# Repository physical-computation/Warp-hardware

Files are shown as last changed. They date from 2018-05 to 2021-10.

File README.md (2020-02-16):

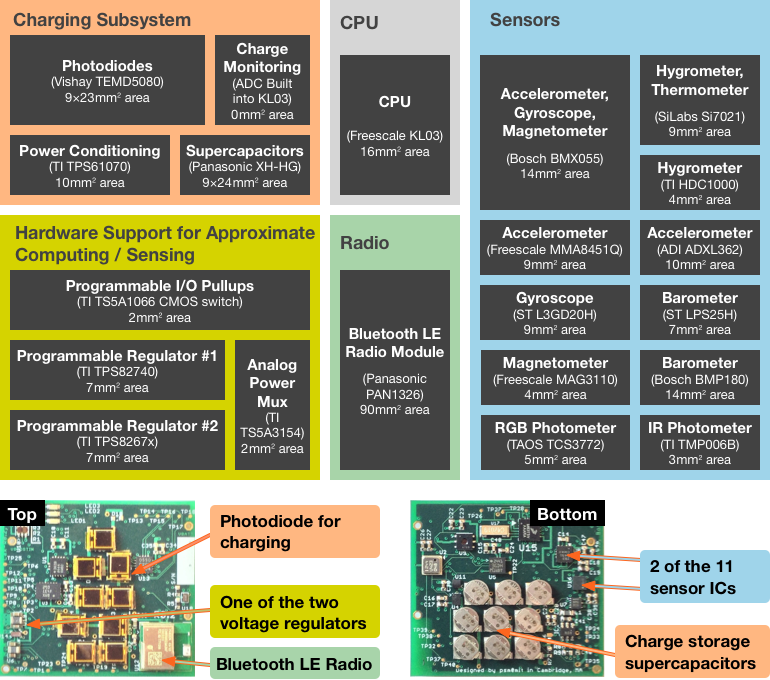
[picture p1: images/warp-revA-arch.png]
Warp


**The Warp hardware platform integrates 21 sensors in a complete system that is 3.6cmx3.3cm**
- - - - 

# Warp
Warp is a hardware platform for efficient multi-modal sensing with adaptive approximation. The hardware contains 11 sensor integrated circuits (ICs) and a total of 21 different sensors. The design includes circuit-level facilities for trading sensor accuracy for power dissipation, and circuit-level facilities for trading sensor communication reliability for power dissipation. The sensors in Warp cover eight sensing modalities: temperature, pressure, 3-axis acceleration, 3-axis angular velocity, 3-axis magnetic flux density, humidity, infrared, color/light (615nm, 525nm, 465nm).

## Prerequisites
We provide the hardware design files in the Eagle CAD format. You can use the free version of Eagle for MacOS, Linux, Windows to view the files. The design is a 10-layer PCB. You will need the full version of Eagle to make modifications. [For academics, the full version of Eagle (Eagle Professional) is completely free](https://knowledge.autodesk.com/support/eagle/learn-explore/caas/sfdcarticles/sfdcarticles/Eagle-Education.html). For non-university hobbyists, Eagle is relatively inexpensive and can also be purchased on a month-at-a-time subscription.

We also provide the hardware design files as Gerbers. You can use any of the numerous free Gerber viewers to view the design.

## Getting boards manufactured
The repository contains detailed instructions for getting the boards manufactured. We provide a pre-populated BOM file with part numbers for purchasing the components from Mouser. Before getting your own boards manufactured, it is worthwhile getting in touch with us for a brief discussion of things to be careful about in providing instructions to your board assembly house.

## Adapting the designs
We license the Warp hardware designs under a BSD license. See details in [LICENSE.txt](https://github.com/physical-computation/Warp-hardware/blob/master/LICENSE.txt).

## Generating Gerbers for manufacturing
The repository comes with the Gerber files pre-generated. You can generate your own Gerber files and drill files for manufacturing using Eagle.

## Getting boards assembled
Basic [BOM](https://github.com/physical-computation/Warp-hardware/blob/master/revA/bom/mouser/warp-revA-bom.xlsx) (uses Mouser for components).

# Implementation and Debug
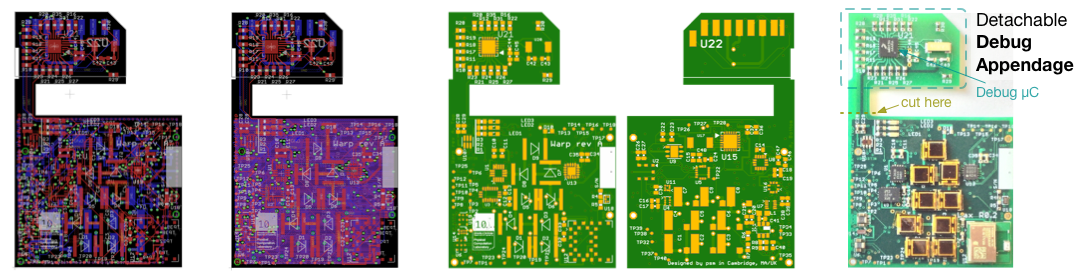
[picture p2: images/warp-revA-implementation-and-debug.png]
Warp


# Mechanical CAD Models for Board and Enclosures
The repository also contains a mechanical CAD model for the board and designs for enclosures, in Autodesk Fusion 360 format. [For academics, the full version of Autodesk Fusion 360 is completely free](https://www.autodesk.co.uk/products/fusion-360/students-teachers-educators). For non-university hobbyists, Fusion 360 is relatively inexpensive and can be purchased on a month-at-a-time subscription.

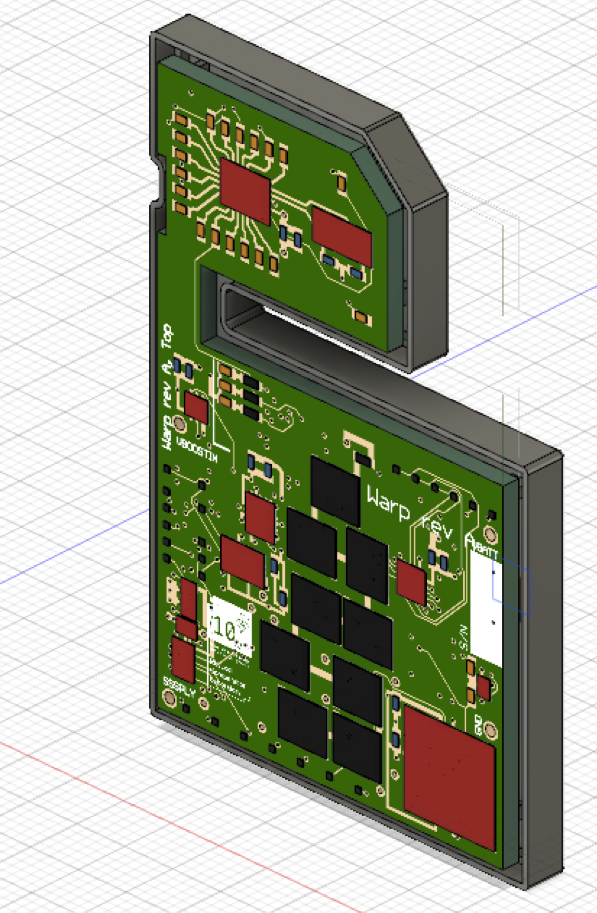
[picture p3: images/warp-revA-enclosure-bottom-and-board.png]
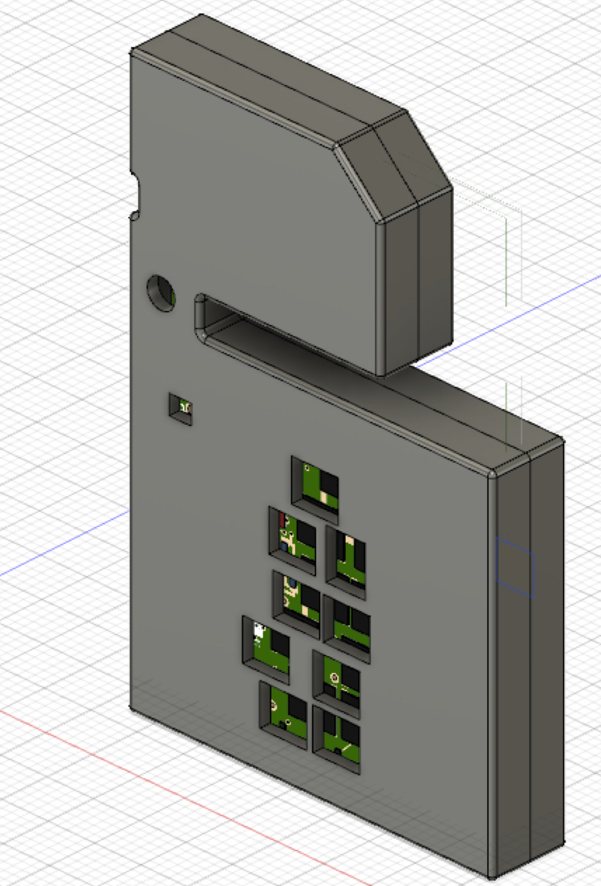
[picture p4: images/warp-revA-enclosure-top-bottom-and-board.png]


## Getting firmware
You can obtain baseline firmware for the Warp platform from the [Warp firmware](https://github.com/physical-computation/Warp-firmware) repository.

## Bugs
See the GitHub issues for a complete list. Before getting your own boards manufactured, it is worthwhile getting in touch with us for a brief discussion of things to be careful about in providing instructions to your board assembly house and hints for getting the firmware running on Warp for the first time.

### If you use Warp in your research, please cite it as:
Phillip Stanley-Marbell and Martin Rinard. “A Hardware Platform for Efficient Multi-Modal Sensing with Adaptive Approximation”. ArXiv e-prints (2018). arXiv:1804.09241.

**BibTeX:**
```
@ARTICLE{1804.09241,
	author = {Stanley-Marbell, Phillip and Rinard, Martin},
	title = {A Hardware Platform for Efficient Multi-Modal 
	Sensing with Adaptive Approximation},
	journal = {ArXiv e-prints},
	archivePrefix = {arXiv},
	eprint = {1804.09241},
	year = 2018,
}
```
Phillip Stanley-Marbell and Martin Rinard. “Warp: A Hardware Platform for Efficient Multi-Modal Sensing with Adaptive Approximation”. IEEE Micro, Volume 40 , Issue 1 , Jan.-Feb. 2020.

**BibTeX:**
```
@ARTICLE{8959350,
	author = {P. {Stanley-Marbell} and M. {Rinard}}, 
	title = {Warp: A Hardware Platform for Efficient Multi-Modal
	Sensing with Adaptive Approximation},
	journal = {IEEE Micro},
	year = {2020}, 
	volume = {40}, 
	number = {1}, 
	pages = {57-66}, 
	ISSN = {1937-4143}, 
	month = {Jan},
}
```
### Acknowledgements
This research is supported by an Alan Turing Institute award TU/B/000096 under EPSRC grant EP/N510129/1, by Royal Society grant RG170136, and by EPSRC grants EP/P001246/1 and EP/R022534/1.

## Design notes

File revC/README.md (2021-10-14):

## Overview
Warp Revision C adds support for a replaceable battery on a JST-PH connector, battery charging via USB, and a new Bluetooth LE module.

JPEG image-622FEEC11206-1

## Switch Settings
- Switch S1: Position 1: OFF; Position 2: OFF
- Switch S2: Position 1, OFF; Position 2: ON

## Battery
JST-PH connector. Polarity: When looking at the top surface of the Warp Revision C board (surface with logo and serial number), the red (positive) conductor will be on the left and the black (negative) conductor will be on the right:

JPEG image-622FEEC11206-1 copy

## Connecting via Bluetooth LE
You can connect to Warp using the BGX Commander app on [iOS](https://apps.apple.com/us/app/bgxcommander/id1350920514) and [Android](https://play.google.com/store/apps/details?id=com.silabs.bgxcommander&hl=en_GB&gl=US) (and using similar facilities on Linux, Windows, and macOS):

IMG_2E5A884E4DB7-1

Once connected, select your Warp from the list of devices and you get a terminal into the Warp prompt (or if your firmware is compiled to enable `WARP_BUILD_BOOT_TO_CSVSTREAM`, you get the CSV stream):



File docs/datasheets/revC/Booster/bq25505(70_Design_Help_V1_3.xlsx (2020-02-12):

User Input | VBIAS | 1.21 | V
Fixed
 | Comparator threshold for VSTOR of charger. |  |  |  |  | Comparator threshold voltages indicating when |  |  |  |  | For the bq25570 only, comparator threshold |  |  |  |  | Maximum power point threshold, e.g. ~0.7-0.8 of
 | Typically the max storage element voltage, |  |  |  |  | VSTOR has risen above VBAT_OK_HYST or fallen |  |  |  |  | for VOUT of buck converter. |  |  |  |  | solar panel's open circuit voltage.
 | e.g. 4.2V for LiIon battery. |  |  |  |  | below VBAT_OK.
 | VBAT_UV < VBAT_OV < 5.5V |  |  |  |  | VBAT_OV > VBAT_OK_HYST > VBAT_UV |  |  |  |  | 1.3V < VOUT < VBAT_OV |  |  |  |  | MPPT
Desired |  |  |  |  |  | RSUM1 | 13 | MW |  |  |  |  |  |  |  | RSUM1 | 20 | MW
Desired | RSUM1 | 13 | MW |  |  | VBAT_OK | 2.2 | V | > VBAT_UV |  | RSUM1 | 13 | MW |  |  | VIN_DC(OC) | 1.6 | V | Open Circuit Volts
Desired | VBAT_OV | 2.6 | V |  |  | VBAT_OK_HYST | 2.44 | V | > VBAT_OK |  | VOUT | 3.8 | V |  |  | VREF_SAMP | 1.5 | V | MPP voltage
 |  |  |  |  |  |  |  | closest 1% resistor1 |  |  |  |  |  |  |  |  |  | closest 1% resistor1
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

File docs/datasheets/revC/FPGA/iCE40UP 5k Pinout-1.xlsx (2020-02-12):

# Pin Out For iCE5UP5K (iCE40 UltraPlus - 5K)
# Revision 0.4 - Remove FWG49
# Revision 1.1 - Fix RGB pins, swapped C5 & A5 pins as well as 39 & 41
# Updated Jun 19, 2017
FNC | Pin Type | BANK | Differential Pair | UWG30 | SG48
IOB_0a | PIO | 2 |  | E5 | 46
IOB_2a | DPIO | 2 | TRUE_of_IOB_3b | D5 | 47
IOB_3b_G6 | DPIO/GBIN | 2 | COMP_of_IOB_2a | F5 | 44
IOB_4a | DPIO | 2 | TRUE_of_IOB_5b | - | 48
IOB_5b | DPIO | 2 | COMP_of_IOB_4a | - | 45
IOB_6a | PIO | 2 |  | - | 2
IOB_8a | DPIO | 2 | TRUE_of_IOB_9b | - | 4
IOB_9b | DPIO | 2 | COMP_of_IOB_8a | E4 | 3
IOB_10a | DPIO | 1 | TRUE_of_IOB_11b | C3 | -
IOB_11b_G5 | DPIO/GBIN | 1 | COMP_of_IOB_10a | F4 | -
creset_b | CONFIG | 1 |  | F3 | 8
IOB_12a_G4_CDONE | CONFIG/DPIO/GBIN | 1 | TRUE_of_IOB_13b | D3 | -
CDONE | CONFIG | 1 |  | - | 7
IOB_13b | DPIO | 1 | COMP_of_IOB_12a | E3 | 6
IOB_16a | PIO | 1 |  | - | 9
IOB_18a | PIO | 1 |  | - | 10
IOB_20a | PIO | 1 |  | - | 11
IOB_22a | DPIO | 1 | TRUE_of_IOB_23b | - | 12
IOB_23b | DPIO | 1 | COMP_of_IOB_22a | - | 21
IOB_24a | DPIO | 1 | TRUE_of_IOB_25b | B1 | 13
IOB_25b_G3 | DPIO/GBIN | 1 | COMP_of_IOB_24a | F2 | 20
IOB_29b | PIO | 1 |  | - | 19
IOB_31b | PIO | 1 |  | - | 18
IOB_32a_SPI_SO | DPIO/CONFIG_SPI | 1 |  | F1 | 14
IOB_33b_SPI_SI | DPIO/CONFIG_SPI | 1 |  | E1 | 17
IOB_34a_SPI_SCK | DPIO/CONFIG_SPI | 1 |  | D1 | 15
IOB_35b_SPI_SS | DPIO/CONFIG_SPI | 1 |  | C1 | 16
VCCPLL | VCCPLL |  |  | B2 | 29
IOT_36b | DPIO/I3C | 0 | COMP_of_IOT_37a | A1 | 25
IOT_37a | DPIO/I3C | 0 | TRUE_of_IOT_36b | A2 | 23
IOT_38b | DPIO | 0 | COMP_of_IOT_39a | - | 27
IOT_39a | DPIO | 0 | TRUE_of_IOT_38b | - | 26
IOT_41a | PIO | 0 |  | - | 28
IOT_42b | DPIO | 0 | COMP_of_IOT_43a | - | 31
IOT_43a | DPIO | 0 | TRUE_of_IOT_42b | - | 32
IOT_44b | DPIO | 0 | COMP_of_IOT_45a | - | 34
IOT_45a_G1 | DPIO/GBIN | 0 | TRUE_of_IOT_44b | - | 37
IOT_46b_G0 | DPIO/GBIN | 0 |  | B3 | 35
IOT_47a | PIO | 0 |  | A4 | -
IOT_48b | DPIO | 0 | COMP_of_IOT_49a | - | 36
IOT_49a | DPIO | 0 | TRUE_of_IOT_48b | - | 43
IOT_50b | DPIO | 0 | COMP_of_IOT_51a | - | 38
IOT_51a | DPIO | 0 | TRUE_of_IOT_50b | - | 42
RGB2 | LED | 0 |  | C5 | 41
RGB1 | LED | 0 |  | B5 | 40
RGB0 | LED | 0 |  | A5 | 39
GND | GND | GND |  | B4 | Paddle
GND | GND | GND |  | E2 | Paddle
GND | GND | GND |  | - | Paddle
VCC | VCC | VCC |  | C2 | 5
VCC | VCC | VCC |  | - | 30
VCCIO_0 | VCCIO | 0 |  | A3 | 33
SPI_Vccio1 | VCCIO | 1 |  | D2 | 22
VCCIO_2 | VCCIO | 2 |  | C4 | 1
VPP_2V5 | VPP | VPP |  | D4 | 24
*SG48 GND is connected to package paddle

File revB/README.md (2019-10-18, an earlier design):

# Switch settings

## Power from USB and Sensors Enabled
```
S1.1 (top): on
S1.2: on
S1.3: off
S1.4: off

S2.1 (top): off
S2.2: off
S2.3: off
S2.4: on
``` 
## Power from Vias and Sensors Enabled
```
S1.1 (top): on
S1.2: on
S1.3: off
S1.4: off

S2.1 (top): off
S2.2: off
S2.3: off
S2.4: off
```

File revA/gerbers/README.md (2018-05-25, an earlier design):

Warp revision A, Gerber files
======================

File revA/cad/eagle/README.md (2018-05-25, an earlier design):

Warp revision A, Eagle CAD files
=========================

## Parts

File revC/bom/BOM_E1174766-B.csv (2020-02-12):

Reference: | E1174766-B
Date: | Mon Feb 10 09:20:12 GMT+000 2020
Generated by: | Eurocircuits PCBA Visualizer
Reference designators | Quantity | MPN | Manufacturer | Description
J1 | 1 | PRT-08612 | Sparkfun | JST Right Angle Connector, 2-SMD
BT:C1, DP:C1, DP:C2, DP:C3, DP:C4, FP:C3, FP:C4, FP:C7, MP:C1, MP:C5, SA:C1, SA:C3, SA:C6, SA:C8, SB:C1, SB:C3, SB:C4, SB:C7, SB:C9, SB:C11, SB:C12, SB:C13, SB:C16, SB:C17, SB:C19, USB:C2 | 26 | GPC0603104 | Generic part | 0603, Cap 100.0nF, 50V, 10.0%, X7R
PV:C11, RT:C1 | 2 | GPC0603104 | Generic part | 0603, Cap 100.0nF, 50V, 10.0%, X7R
PV:R3 | 1 | GPR06031M3 | Generic part | 0603, Res 1.3MOhm, 75V, 1.0%, 100mW
FP:R2 | 1 | GPR0603100R | Generic part | 0603, Res 100.0Ohm, 50V, 1.0%, 100mW
CH:R3, FP:R1, FP:R3, MP:R1, MP:R2, MP:R4, RT:R1, RT:R2 | 8 | GPR060310K | Generic part | 0603, Res 10.0kOhm, 50V, 1.0%, 100mW
SB:C6 | 1 | GPC0603103 | Generic part | 0603, Cap 10.0nF, 50V, 10.0%, X7R
PV:C12 | 1 | GCM188R72A103KA37D | Murata | 10000pF ±10% 100V Ceramic Capacitor X7R 0603 (1608 Metric),AEC-Q200,Automotive
FP:C5, FP:C6, SB:C5 | 3 | GPC0603106-10 | Generic part | 10 uF +/- 10% 10 V X5R 0603 Multilayer Ceramic Capacitors MLCC - SMD/SMT T&R GP
RG:C1, RG:C2 | 2 | GCM21BR71A106KE22K | Murata Electronics North America | 10µF ±10% 10V Ceramic Capacitor X7R 0805 (2012 Metric) AEC-Q200, Automotive
PV:L2 | 1 | 744029100 | Wurth | 10µH Shielded Wirewound Inductor 650mA 470 mOhm Max Nonstandard
BT:C2, FP:C1, FP:C2, SA:C2, SA:C4, SA:C7, SA:C9, SB:C2, SB:C8, SB:C18 | 10 | GPC0603105 | Generic part | 0603, Cap 1uF, 50V, 10.0%, X5R
CH:C1 | 1 | GPC0805105 | Generic part | 0805, Cap 1uF, 50V, 10.0%, X7R
RG:L1 | 1 | 744025002 | Wurth Electronics Inc. | 2.2µH Shielded Wirewound Inductor 1.8A 66mOhm Max Nonstandard
CH:R1 | 1 | RC0603FR-072K94L | Yageo | Resistor, Chip, General Purpose 2.94K Ohm 1/10W 1%
SB:C15 | 1 | GPC0603223 | Generic part | 0603, Cap 22.0nF, 50V, 10.0%, X7R
PV:C13 | 1 | JMK212BJ226KG-T | Taiyo Yuden | 22µF ±10% 6.3V Ceramic Capacitor X5R 0805 (2012 Metric)
PV:L1 | 1 | 744031220 | Würth Elektronik | 22µH Shielded Wirewound Inductor 510mA 450 mOhm Max
RG:R1, RG:R2, RG:R3, RG:R4, RG:R5 | 5 | GPR06032M | Generic part | 0603, Res 2.0MOhm, 75V, 1.0%, 100mW
CH:R4, CH:R5 | 2 | GPR06032K | Generic part | 0603, Res 2.0kOhm, 75V, 1.0%, 100mW
MP:C3, MP:C4 | 2 | 06035A330FAT2A | AVX | SMD Multilayer Ceramic Capacitor, 33 pF, 50 V, 0603 [1608 Metric], ± 1%, C0G / NP0, AVX 0603 MLCC
PV:R1 | 1 | RC0603FR-074M02L | Yageo | 4.02 MOhms ±1% 0.1W, 1/10W Chip Resistor 0603 (1608 Metric) Moisture Resistant Thick Film
PV:R7 | 1 | CRCW06034M22FKEA | Vishay | 4.22 MOhms ±1% 0.1W, 1/10W Chip Resistor 0603 (1608 Metric) Automotive AEC-Q200 Thick Film
CH:R2 | 1 | RC0603FR-074K32L | Yageo | 4.32 kOhms ±1% 0.1W, 1/10W Chip Resistor 0603 (1608 Metric) Moisture Resistant Thick Film
MP:R3 | 1 | GPR06034K7 | Generic part | 0603, Res 4.7kOhm, 50V, 1.0%, 100mW
MP:C2, SA:C5, SB:C10, SB:C14, USB:C1 | 5 | GPC0603475-10 | Generic part | 4.7µF ±10% 10V Ceramic Capacitor X5R 0603 (1608 Metric)
CH:C2, CH:C3, PV:C9, PV:C10 | 4 | GRM21BZ7YA475ME15L | Murata | Multilayer Ceramic Capacitors MLCC - SMD/SMT
PV:R4 | 1 | CRCW06035M36FKEA | Vishay Dale | 5.36 MOhms ±1% 0.1W, 1/10W Chip Resistor 0603 (1608 Metric) Automotive AEC-Q200 Thick Film
CH:R6 | 1 | RC0603FR-0756K2L | Yageo | 56.2 kOhms ±1% 0.1W, 1/10W Chip Resistor 0603 (1608 Metric) Moisture Resistant Thick Film
PV:R5 | 1 | CRCW06036M49FKEA | Vishay Dale | 6.49 MOhms ±1% 0.1W, 1/10W Chip Resistor 0603 (1608 Metric) Automotive AEC-Q200 Thick Film
USB:FB1 | 1 | 742792651 | Würth Elektronik | FERRITE BEAD 600 OHM 0603 1LN
PV:R6 | 1 | CRCW06038M87FKEA | Vishay Dale | 8.87 MOhms ±1% 0.1W, 1/10W Chip Resistor 0603 (1608 Metric) Automotive AEC-Q200 Thick Film
PV:R2 | 1 | CRCW06039M09FKEAC | Vishay Dale | 9.09 MOhms ±1% 0.1W, 1/10W Chip Resistor 0603 (1608 Metric) Thick Film
SA:U1 | 1 | ADXL362BCCZ-RL7 | Analog Devices | IC, Micropower, 3-Axis, 2 g/4 g/8 g Digital Output MEMS Accelerometer
MP:U2 | 1 | AT45DB641E-MHN-Y | Adesto Technologies | FLASH Memory IC 64Mb (264 Bytes x 32K pages) SPI 85MHz 8-UDFN (5x6)
BT:U1 | 1 | BGX13S22GA-V21R | Silicon Labs | BLUETOOTH 5 CABLE REPLACEMENT SI
SA:U4 | 1 | BME680 | Bosch-Sensortec | Gas, Humidity, Pressure, Temperature Sensor I²C Output
SA:U2 | 1 | BMX055 | BOSCH Sensortec | Accelerometer, Gyroscope, Magnetometer, 3 Axis Sensor I²C, SPI Output
CH:U1 | 1 | BQ24230RGTR | Texas Instrument | IC LI-ION CHGR 4.4V 16-QFN
PV:U1 | 1 | BQ25570RGRR | Texas Instruments | Battery Management Low Pwr Harvester Pwr Mgmt IC
SA:U3 | 1 | CCS811B-JOPR5K | AMS | CCS811B-JOPR5K LGA10 LF T&R
S1, S2 | 2 | CHS-02TA | Nidec Copal Electronics | Dip Switch SPST 2 Position Surface Mount Slide (Standard) Actuator 100mA 6VDC
MP:Y1 | 1 | CM51932768DZFT | Citizen Finetech Miyota | 32.768kHz ±20ppm Crystal 12.5pF 70 kOhm -40°C ~ 85°C Surface Mount 2-SMD, No Lead
J5 | 1 | FTSH-105-01-LM-DV-K | Samtec | 10 Positions Header, Cuttable Connector Surface Mount
PV:C1, PV:C2, PV:C3, PV:C4, PV:C5, PV:C6, PV:C7, PV:C8 | 8 | CPX3225A752D | Seiko | 7.5mF (EDLC) Supercapacitor 2.6V 1210 (3225 Metric) 25Ohm @ 1kHz
J4 | 1 | DF40C-20DP-0.4V(51) | Hirose | 20 Position Connector Plug, Outer Shroud Contacts Surface Mount Gold
S3 | 1 | EVP-AYG0BA | Panasonic | Tactile Switch SPST-NO Top Actuated Surface Mount
SB:U4 | 1 | FXOS8700CQR1 | NXP USA Inc. | Accelerometer, Magnetometer, 3 Axis Sensor I²C, SPI Output
CH:D1 | 1 | APT1608LZGCK | Kingbright | Green 525nm LED Indication - Discrete 2.65V 0603 (1608 Metric)
SB:U7 | 1 | HDC1000YPAR | Texas Instruments | Humidity Temperature Sensor 0 ~ 100% RH I²C ±3% RH 15s Surface Mount
FP:U2 | 1 | ICE40UP5K-UWG30ITR1K | Lattice Semiconductor | IC FPGA 21 I/O 30WLCSP
BT:Y1 | 1 | LFXTAL050789Cutt | IQD | Crystals 32.7680kHz 2.0 x 1.2 x 0.6mm
DP:U1, DP:U2, DP:U3, DP:U4 | 4 | ISL23415TFRUZ-T7A | Intersil | Digital Potentiometer 100k Ohm 1 Circuit 256 Taps SPI Interface 10-UTQFN (2.1x1.6)
SB:U2 | 1 | L3GD20HTR | STMicroelectronics | Gyroscope X (Pitch), Y (Roll), Z (Yaw) ±245, 500, 2000 6.25Hz ~ 400Hz I²C, SPI 16-LGA (3x3)
SB:U5 | 1 | LPS25HBTR | STMicroelectronics | Pressure Sensor 3.77 PSI ~ 18.27 PSI (26 kPa ~ 126 kPa) Absolute 24 b 10-VFLGA
CH:U2, RG:U2, RG:U3 | 3 | MAX40200ANS+T | Maxim Integrated | OR Controller Source Selector Switch P-Channel 1:1 4-WLP (0.73x0.73)
FP:U1 | 1 | MCP1811AT-012/TT | Microchip Technology | Linear Voltage Regulator IC 1 Output 150mA SOT-23-3
MP:U1 | 1 | MKL03Z32VFK4R | NXP | Kinetis KL03 Microcontroller IC 32-Bit 48MHz 32KB (32K x 8) FLASH 24-QFN (4x4)
SB:U1 | 1 | MMA8451QT | NXP Semiconductors | Accelerometer X, Y, Z Axis ±2g, 4g, 8g 0.78Hz ~ 400Hz 16-QFN
USB:P1 | 1 | 47346-0001 | Molex | Connector, Micro USB Type B, Receptacle, Bottom Mount
J2, J3 | 2 | PRT-14417 | SparkFun | QWIIC JST CONNECTOR - SMD 4-PIN
RT:U1 | 1 | RV-8803-C7-32.768k-3PPM-TA-QA | Micro Crystal | Real Time Clock 32.768 kHz +/-3 PPM I2C -40/+85C
CH:D2 | 1 | APT1608LSECK/J3-PRV | Kingbright | Red 625nm LED Indication - Discrete 1.8V 0603 (1608 Metric)
SB:U6 | 1 | SI4705-D50-GM | Silicon Labs | - RF Receiver FM 64MHz ~ 108MHz PCB, Surface Mount 20-QFN (3x3)
SB:U3 | 1 | SI7021-A20-IM1 | Silicon Labs | Humidity Temperature Sensor 0 ~ 100% RH I²C ±3% RH 18S Surface Mount
SA:U5 | 1 | TCS34725FN | AMS | Color Sensor 16 b Gain Control, Interrupt, Sleep Mode 6-SMD Module
RG:U1 | 1 | TPS62740DSSR | Texas Instruments | DCS-Control™ Converter, Bluetooth (BLT) Voltage Regulator IC 1 Output 12-WSON (3x2)

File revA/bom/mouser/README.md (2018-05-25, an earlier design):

Warp revision A, Bill of Materials (BOM)
==============================

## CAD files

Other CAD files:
revA/cad/fusion360/enclosure-design.f3d
revA/cad/fusion360/warp-revA.f3d
revB/cad/fusion360/Enclosure-Design-RevB.f3d
revB/cad/fusion360/Square-Enclosure-Design-RevB-Bolts.f3d
revB/cad/fusion360/Square-Enclosure-Design-RevB-NoBolts.f3d
revB/cad/fusion360/Switch-Design-RevB.f3d
revB/cad/fusion360/Wristband-Design-revB.f3d
revB/cad/fusion360/warp-revB.f3d

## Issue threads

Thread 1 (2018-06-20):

Create a case / enclosure for Warp revision A board

lilrabbits, 2018-06-20:

phillipstanleymarbell, 2018-06-28:
Addressed by #3 .

Closed 2018-06-28.

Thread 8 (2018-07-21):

Add a README.md to Warp-hardware/revB/cad/fusion360/ with screen captures of each of the enclosure designs

phillipstanleymarbell, 2018-07-21:
Add a README.md to `Warp-hardware/revB/cad/fusion360/` with screen captures of each of the designs from Fusion360 (like the ones in the top-level README.md or something similar/better) to give an idea of what the different enclosures are.

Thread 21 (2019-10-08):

Power from USB and Sensors Enabled is wrong

JamesTimothyMeech, 2019-10-08:
The warp bard constantly reboots with the switches in this configuration.

phillipstanleymarbell, 2019-10-08:
Can you be more specific?

phillipstanleymarbell, 2019-10-08:
Fixed in #22.

Closed 2019-10-08.

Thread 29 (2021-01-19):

Cannot open Rev-A and Rev-C .sch and .brd in latest Eagle (9.6.2)

majianjia, 2021-01-19:
Hi,

I wanted to discuss the hardware with my friend but cannot open the files.

The RevA and C files cannot be opened by the latest Eagle but the RevB is fine.

When trying to open it, Eagle produce an error said something wrong at line 8.
I then opened all three .brd files by a text editor, found that the RevB was built in a newer Eagle while RevA and C were in an older Eagle. I wonder whether this is the case?

Thanks
Jianjia

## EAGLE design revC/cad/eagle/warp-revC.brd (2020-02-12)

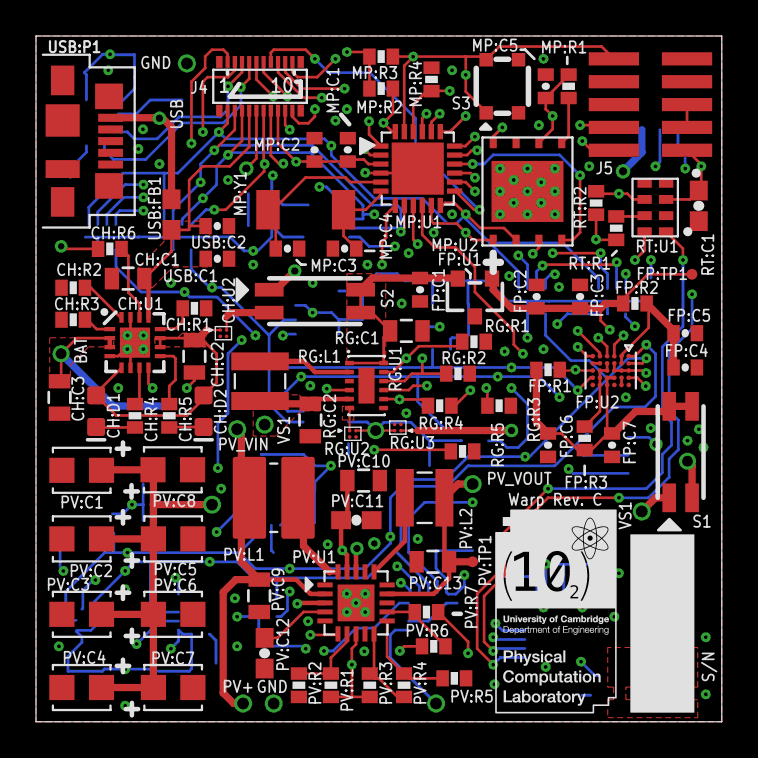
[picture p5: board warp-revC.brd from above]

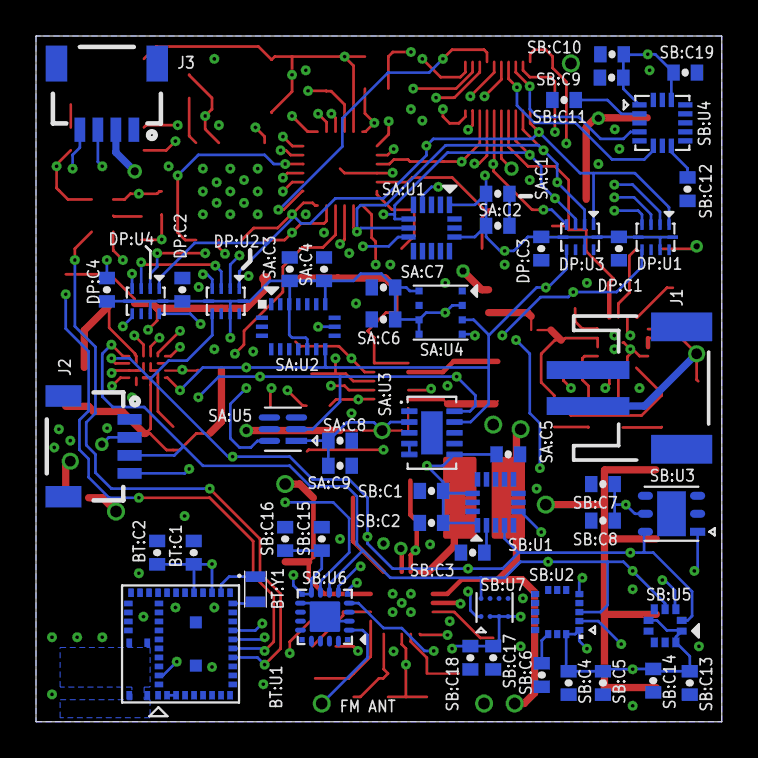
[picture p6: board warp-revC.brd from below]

Board: 10 copper layers, 38.1 x 38.1 mm, 141 parts (55 on the bottom side), 73 nets.

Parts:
BT:C1: 0.1uF; 0402-CAP
BT:C2: 1uF; 0402-CAP
BT:U1: BGX13S22GA-V21R; BGX13S
BT:Y1: IQXC-25
CH:C1: 1uF; 0805
CH:C2, CH:C3: 4.7uF; 0805
CH:D1: Green; LED-0603
CH:D2: Red; LED-0603
CH:R1: 2.94k; 0402-RES
CH:R2: 4.32k; 0402-RES
CH:R3: 10k; 0402-RES
CH:R4, CH:R5: 2k; 0402-RES
CH:R6: 56.2k; 0402-RES
CH:U1: BQ24230VQFN; PVQFN-N16
CH:U2: MAX40200; DSBGA
DP:C1, DP:C2, DP:C3, DP:C4: 0.1uF; 0402-CAP
DP:U1, DP:U2, DP:U3, DP:U4: ISL23415UTQFN; ISL23415
FP:C1, FP:C2: 1uF; 0402-CAP
FP:C3, FP:C4, FP:C7: 0.1uF; 0402-CAP
FP:C5, FP:C6: 10uF; 0402-CAP
FP:R1, FP:R3: 10k; 0402-RES
FP:R2: 100; 0402-RES
FP:TP1: TPSTP06R; TP06R
FP:U1: MCP1811AT-012/TTSOT-23-3; SOT23-3
FP:U2: ICE40UP5K-UWG30; LATTICE-WLCSP-30
J1: JST-2-SMD
J2, J3: QIIC connector; 1X04_1MM_RA
J4: DF40FC-20DP-0.4V(51); DF40C-20DP-0.4V(51)
J5: FTSH-105-01-XXX-DV-K
MP:C1, MP:C5: 0.1uF; 0402-CAP
MP:C2: 4.7uF; 0402-CAP
MP:C3, MP:C4: 33pF; 0402-CAP
MP:R1, MP:R2, MP:R4: 10k; 0402-RES
MP:R3: 4.7k; 0402-RES
MP:U1: MKL03Z32VFK4RQFN24; MKL03Z32VFK4R
MP:U2: AT45DB641E-MHN-Y; UDFN
MP:Y1: CM519-SMD; CM519
PV:C1, PV:C2, PV:C3, PV:C4, PV:C5, PV:C6, PV:C7, PV:C8: CPX3225A7552D; CPX3225A752D
PV:C9, PV:C10: 4.7uF; 0805
PV:C11: 0.1uF; 0603-CAP
PV:C12: 10nF; 0603-CAP
PV:C13: 22uF; 0805
PV:L1: 22uH; WE-TPC_3816
PV:L2: 10uH; WE-TPC_2811/2813_OLD
PV:R1: 4.02M; 0402-RES
PV:R2: 9.09M; 0402-RES
PV:R3: 1.3M; 0402-RES
PV:R4: 5.36M; 0402-RES
PV:R5: 6.49M; 0402-RES
PV:R6: 8.87M; 0402-RES
PV:R7: 4.22M; 0402-RES
PV:TP1: TPSTP06R; TP06R
PV:U1: BQ25570PVQFN; BQ25570
RG:C1, RG:C2: 10uF; 0805
RG:L1: 2.2uH; WE-TPC_2828_OLD
RG:R1, RG:R2, RG:R3, RG:R4, RG:R5: 2M; 0402-RES
RG:U1: TPS6274XWSON; WSON-12
RG:U2, RG:U3: MAX40200; DSBGA
RT:C1: 0.1uF; 0603-CAP
RT:R1, RT:R2: 10k; 0402-RES
RT:U1: RV-8803-C7_RTC; RV-C7
S1, S2: CHS-02_SWITCH
S3: EVPAYG0BAEVPAYG0BA; EVPAYG0BA
SA:C1, SA:C3, SA:C6, SA:C8: 0.1uF; 0402-CAP
SA:C2, SA:C4, SA:C7, SA:C9: 1uF; 0402-CAP
SA:C5: 4.7uF; 0402-CAP
SA:U1: ADXL362
SA:U2: BMX055
SA:U3: CCS811; SON60P270X400X110-11N
SA:U4: BME680LGA; BME680
SA:U5: TCS34725FN; TCS3772
SB:C1, SB:C3, SB:C4, SB:C7, SB:C9, SB:C11, SB:C12, SB:C13, SB:C16, SB:C17, SB:C19: 0.1uF; 0402-CAP
SB:C2, SB:C8, SB:C18: 1uF; 0402-CAP
SB:C5: 10uF; 0402-CAP
SB:C6: 10nF; 0402-CAP
SB:C10, SB:C14: 4.7uF; 0402-CAP
SB:C15: 22nF; 0402-CAP
SB:U1: MMA8451Q
SB:U2: L3GD20H
SB:U3: SI7021
SB:U4: FXOS8700CQ; QFN16
SB:U5: LPS25H
SB:U6: SI4705
SB:U7: HDC1000
USB:C1: 4.7uF; 0402-CAP
USB:C2: 0.1uF; 0402-CAP
USB:FB1: 600R/1A; 0603
USB:P1: MOLEX_USB_47346-0001MICRO_USB_B; USB-B-MICRO-SMD

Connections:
ADXL362_SPI_CS: MP:U1.P$15, SA:U1.P$8
BAT: CH:C3.1, CH:U1.2, CH:U1.3, J1.2
BGX13S_!RST: BT:U1.44, MP:U1.P$7
BOOST_VBAT: PV:C1.+, PV:C2.+, PV:C3.+, PV:C4.+, PV:C5.+, PV:C6.+, PV:C7.+, PV:C8.+, PV:U1.18
BT:N$1: BT:U1.21, BT:Y1.1
BT:N$2: BT:U1.19, BT:Y1.2
BT:N$3: BT:U1.2, BT:U1.3
CH:BQ24230_OUT: CH:C2.1, CH:D1.A, CH:D2.A, CH:U1.5, CH:U1.10, CH:U1.11, CH:U2.A1
CH:N$1: CH:R2.2, CH:U1.16
CH:N$2: CH:R1.2, CH:U1.12
CH:N$3: CH:R4.1, CH:U1.7
CH:N$4: CH:R3.2, CH:U1.1
CH:N$5: CH:R5.1, CH:U1.9
CH:N$6: CH:D1.C, CH:R4.2
CH:N$7: CH:D2.C, CH:R5.2
CH:N$8: CH:R6.2, CH:U1.14
CHARGE_VOUT: CH:U2.A2, S2.2
CLK32K: MP:U1.P$21, SB:U6.P$9
CRESET_B: FP:R1.1, FP:U2.F3, J4.P$17
FP:ICE40_VCC_PLL: FP:C4.1, FP:C5.1, FP:R2.1, FP:U2.B1, FP:U2.B2
FP:VCC_1V2: FP:C2.1, FP:C3.1, FP:R2.2, FP:TP1.TP, FP:U1.1, FP:U2.A3, FP:U2.B3, FP:U2.C2, FP:U2.C3
FP:VCC_SHUNT: FP:R3.1, FP:U2.D2, FP:U2.D3, FP:U2.E3, FP:U2.E4, FP:U2.E5
FPGA_CS: FP:U2.C1, J4.P$7, MP:U1.P$13
FPGA_VS: FP:C6.1, FP:C7.1, FP:R1.2, FP:R3.2, FP:U2.C4, FP:U2.D4, FP:U2.D5, S1.1', S1.2'
GND: BT:C1.2, BT:C2.2, BT:U1.1, BT:U1.4, BT:U1.5, BT:U1.20, BT:U1.31, BT:U1.45, BT:U1.46, BT:U1.47, BT:U1.48, BT:U1.49, BT:U1.50, BT:U1.51, CH:C1.2, CH:C2.2, CH:C3.2, CH:R1.1, CH:R2.1, CH:R3.1, CH:R6.1, CH:U1.4, CH:U1.6, CH:U1.8, CH:U1.15, CH:U1.EP, CH:U2.B2, DP:C1.2, DP:C2.2, DP:C3.2, DP:C4.2, DP:U1.9, DP:U2.9, DP:U3.9, DP:U4.9, FP:C1.2, FP:C2.2, FP:C3.2, FP:C4.2, FP:C5.2, FP:C6.2, FP:C7.2, FP:U1.3, FP:U2.B4, FP:U2.B5, FP:U2.E2, FP:U2.F2, J1.1, J2.1, J3.1, J4.P$20, J5.3, J5.5, MP:C1.2, MP:C2.2, MP:C3.2, MP:C4.2, MP:C5.2, MP:R4.2, MP:U1.P$4, MP:U1.P$PAD, MP:U2.7, MP:U2.9, PV:C1.-, PV:C2.-, PV:C3.-, PV:C4.-, PV:C5.-, PV:C6.-, PV:C7.-, PV:C8.-, PV:C9.2, PV:C10.2, PV:C11.2, PV:C12.2, PV:C13.2, PV:R2.1, PV:R5.1, PV:R7.1, PV:U1.1, PV:U1.5, PV:U1.9, PV:U1.15, PV:U1.17, PV:U1.21, RG:C1.2, RG:C2.2, RG:R1.1, RG:R2.1, RG:R3.1, RG:R4.1, RG:R5.1, RG:U1.3, RG:U2.B2, RG:U3.B2, RT:C1.2, RT:U1.4, RT:U1.5, S3.B, S3.B', SA:C1.2, SA:C2.2, SA:C3.2, SA:C4.2, SA:C5.2, SA:C6.2, SA:C7.2, SA:C8.2, SA:C9.2, SA:U1.P$12, SA:U1.P$13, SA:U1.P$16, SA:U2.P$4, SA:U2.P$6, SA:U2.P$12, SA:U2.P$17, SA:U2.P$20, SA:U3.1, SA:U3.7, SA:U3.11, SA:U4.1, SA:U4.7, SA:U5.3, SB:C1.2, SB:C2.2, SB:C3.2, SB:C4.2, SB:C5.2, SB:C6.2, SB:C7.2, SB:C8.2, SB:C9.2, SB:C10.2, SB:C11.2, SB:C12.2, SB:C13.2, SB:C14.2, SB:C15.2, SB:C16.2, SB:C17.2, SB:C18.2, SB:C19.2, SB:U1.5, SB:U1.7, SB:U1.10, SB:U1.12, SB:U2.4, SB:U2.9, SB:U2.10, SB:U2.11, SB:U2.12, SB:U2.13, SB:U2.15, SB:U3.2, SB:U4.P$3, SB:U4.P$5, SB:U4.P$7, SB:U4.P$10, SB:U4.P$12, SB:U4.P$13, SB:U4.P$16, SB:U5.3, SB:U5.5, SB:U5.8, SB:U5.9, SB:U6.P$3, SB:U6.P$6, SB:U6.P$12, SB:U6.P$21, SB:U7.B2, USB:C1.2, USB:C2.2, USB:P1.5, USB:P1.S1, USB:P1.S2, USB:P1.S3, USB:P1.S4, USB:P1.S5, USB:P1.S6
I2C0_SCL/UART_TX: BT:U1.14, J4.P$5, MP:U1.P$17, RT:U1.8
I2C0_SDA/UART_RX: BT:U1.13, J4.P$6, MP:U1.P$18, RT:U1.1
I2C1_SCL: DP:U1.6, FP:U2.A4, J3.4, J4.P$1, SA:U2.P$9, SA:U3.10, SA:U4.4, SA:U5.2
I2C1_SDA: DP:U3.6, FP:U2.F4, J3.3, J4.P$2, SA:U2.P$11, SA:U3.9, SA:U4.3, SA:U5.6
I2C2_SCL: DP:U2.6, FP:U2.A2, J2.4, J4.P$3, SB:U1.4, SB:U2.2, SB:U3.6, SB:U4.P$4, SB:U5.2, SB:U6.P$7, SB:U7.A1
I2C2_SDA: DP:U4.6, FP:U2.A1, J2.3, J4.P$4, SB:U1.6, SB:U2.3, SB:U3.1, SB:U4.P$6, SB:U5.4, SB:U6.P$8, SB:U7.A2
ISL23415_SPI_CS: DP:U1.4, DP:U2.4, DP:U3.4, DP:U4.4, J4.P$16, MP:U1.P$20
MP:AT45DB321F_SPI_CS: MP:U1.P$16, MP:U2.4
MP:EXTAL0: MP:C3.1, MP:U1.P$5, MP:Y1.P$1
MP:N$4: MP:R1.1, MP:U2.5
MP:XTAL0: MP:C4.1, MP:U1.P$6, MP:Y1.P$2
PV:LBOOST: PV:L1.2, PV:U1.20
PV:LBUCK: PV:L2.2, PV:U1.16
PV:OK_HYST: PV:R3.1, PV:R4.2, PV:U1.10
PV:OK_PROG: PV:R4.1, PV:R5.2, PV:U1.11
PV:VBAT_OV: PV:R1.1, PV:R2.2, PV:U1.7
PV:VOUT_SET: PV:R6.1, PV:R7.2, PV:U1.12
PV:VRDIV: PV:R1.2, PV:R3.2, PV:R6.2, PV:U1.8
PV:VREF_SAMP: PV:C12.1, PV:U1.4
PV:VSTOR: PV:C10.1, PV:C11.1, PV:U1.3, PV:U1.6, PV:U1.19
PV_VIN: J4.P$15, PV:C9.1, PV:L1.1, PV:U1.2
PV_VOUT: PV:C13.1, PV:L2.1, PV:TP1.TP, PV:U1.14, S2.1
REG_CTRL: MP:U1.P$19, RG:R5.2, RG:U1.4
REG_VIN: FP:C1.1, FP:U1.2, RG:C1.1, RG:U1.1, RG:U1.12, S2.1', S2.2'
REG_VSEL1: MP:U1.P$1, RG:R1.2, RG:U1.11
REG_VSEL2: MP:U1.P$2, RG:R2.2, RG:U1.10
REG_VSEL3: MP:U1.P$9, RG:R3.2, RG:U1.9
REG_VSEL4: MP:U1.P$10, RG:R4.2, RG:U1.8
RG:LOAD: RG:U1.6, RG:U2.A1
RG:SW: RG:L1.1, RG:U1.2
RT:N$3: RT:R1.1, RT:U1.7
RTC_!INT!/RESET_B: J4.P$10, J5.10, MP:R3.1, MP:U1.P$23, RT:R2.1, RT:U1.6, S3.A, S3.A'
SA:N$2: SA:U3.4, SA:U3.5
SB:CAP: SB:C6.1, SB:U2.14
SB:N$1: SB:C3.1, SB:U1.2
SB:N$2: SB:C11.1, SB:U4.P$2
SB:N$3: SB:C12.1, SB:U4.P$8
SI4705_!RST: MP:U1.P$14, SB:U6.P$5
SPI_MISO/UART_RTS: BT:U1.16, DP:U1.2, DP:U2.2, DP:U3.2, DP:U4.2, FP:U2.F1, J4.P$12, MP:U1.P$8, MP:U2.8, SA:U1.P$7
SPI_MOSI/UART_CTS: BT:U1.15, DP:U1.3, DP:U2.3, DP:U3.3, DP:U4.3, FP:U2.E1, J4.P$13, MP:U1.P$11, MP:U2.1, SA:U1.P$6
SPI_SCK: DP:U1.1, DP:U2.1, DP:U3.1, DP:U4.1, FP:U2.D1, J4.P$11, MP:U1.P$12, MP:U2.2, SA:U1.P$4
SWD_CLK: J4.P$9, J5.4, MP:R4.1, MP:U1.P$22
SWD_DIO: J4.P$8, J5.2, MP:R2.1, MP:U1.P$24
USB:VBUS: USB:FB1.2, USB:P1.1
USB_5V: CH:C1.1, CH:U1.13, J4.P$14, USB:C1.1, USB:C2.1, USB:FB1.1
VCC_QIIC: J2.2, J3.2, RG:U3.A1
VS1: J4.P$18, J5.1, MP:C1.1, MP:C2.1, MP:C5.1, MP:R1.2, MP:R2.2, MP:R3.2, MP:U1.P$3, MP:U2.3, MP:U2.6, RG:C2.1, RG:L1.2, RG:U1.5, RT:C1.1, RT:R1.2, RT:R2.2, RT:U1.3, S1.1
VS2: BT:C1.1, BT:C2.1, BT:U1.22, BT:U1.24, DP:C1.1, DP:C2.1, DP:C3.1, DP:C4.1, DP:U1.5, DP:U1.8, DP:U1.10, DP:U2.5, DP:U2.8, DP:U2.10, DP:U3.5, DP:U3.8, DP:U3.10, DP:U4.5, DP:U4.8, DP:U4.10, J4.P$19, RG:U2.A2, RG:U3.A2, S1.2, SA:C1.1, SA:C2.1, SA:C3.1, SA:C4.1, SA:C5.1, SA:C6.1, SA:C7.1, SA:C8.1, SA:C9.1, SA:U1.P$1, SA:U1.P$14, SA:U2.P$3, SA:U2.P$7, SA:U2.P$13, SA:U3.2, SA:U3.6, SA:U4.2, SA:U4.5, SA:U4.6, SA:U4.8, SA:U5.1, SB:C1.1, SB:C2.1, SB:C4.1, SB:C5.1, SB:C7.1, SB:C8.1, SB:C9.1, SB:C10.1, SB:C13.1, SB:C14.1, SB:C15.1, SB:C16.1, SB:C17.1, SB:C18.1, SB:C19.1, SB:U1.1, SB:U1.14, SB:U2.1, SB:U2.5, SB:U2.16, SB:U3.5, SB:U4.P$1, SB:U4.P$14, SB:U5.1, SB:U5.6, SB:U5.10, SB:U6.P$10, SB:U6.P$11, SB:U7.B1, SB:U7.C1, SB:U7.D1

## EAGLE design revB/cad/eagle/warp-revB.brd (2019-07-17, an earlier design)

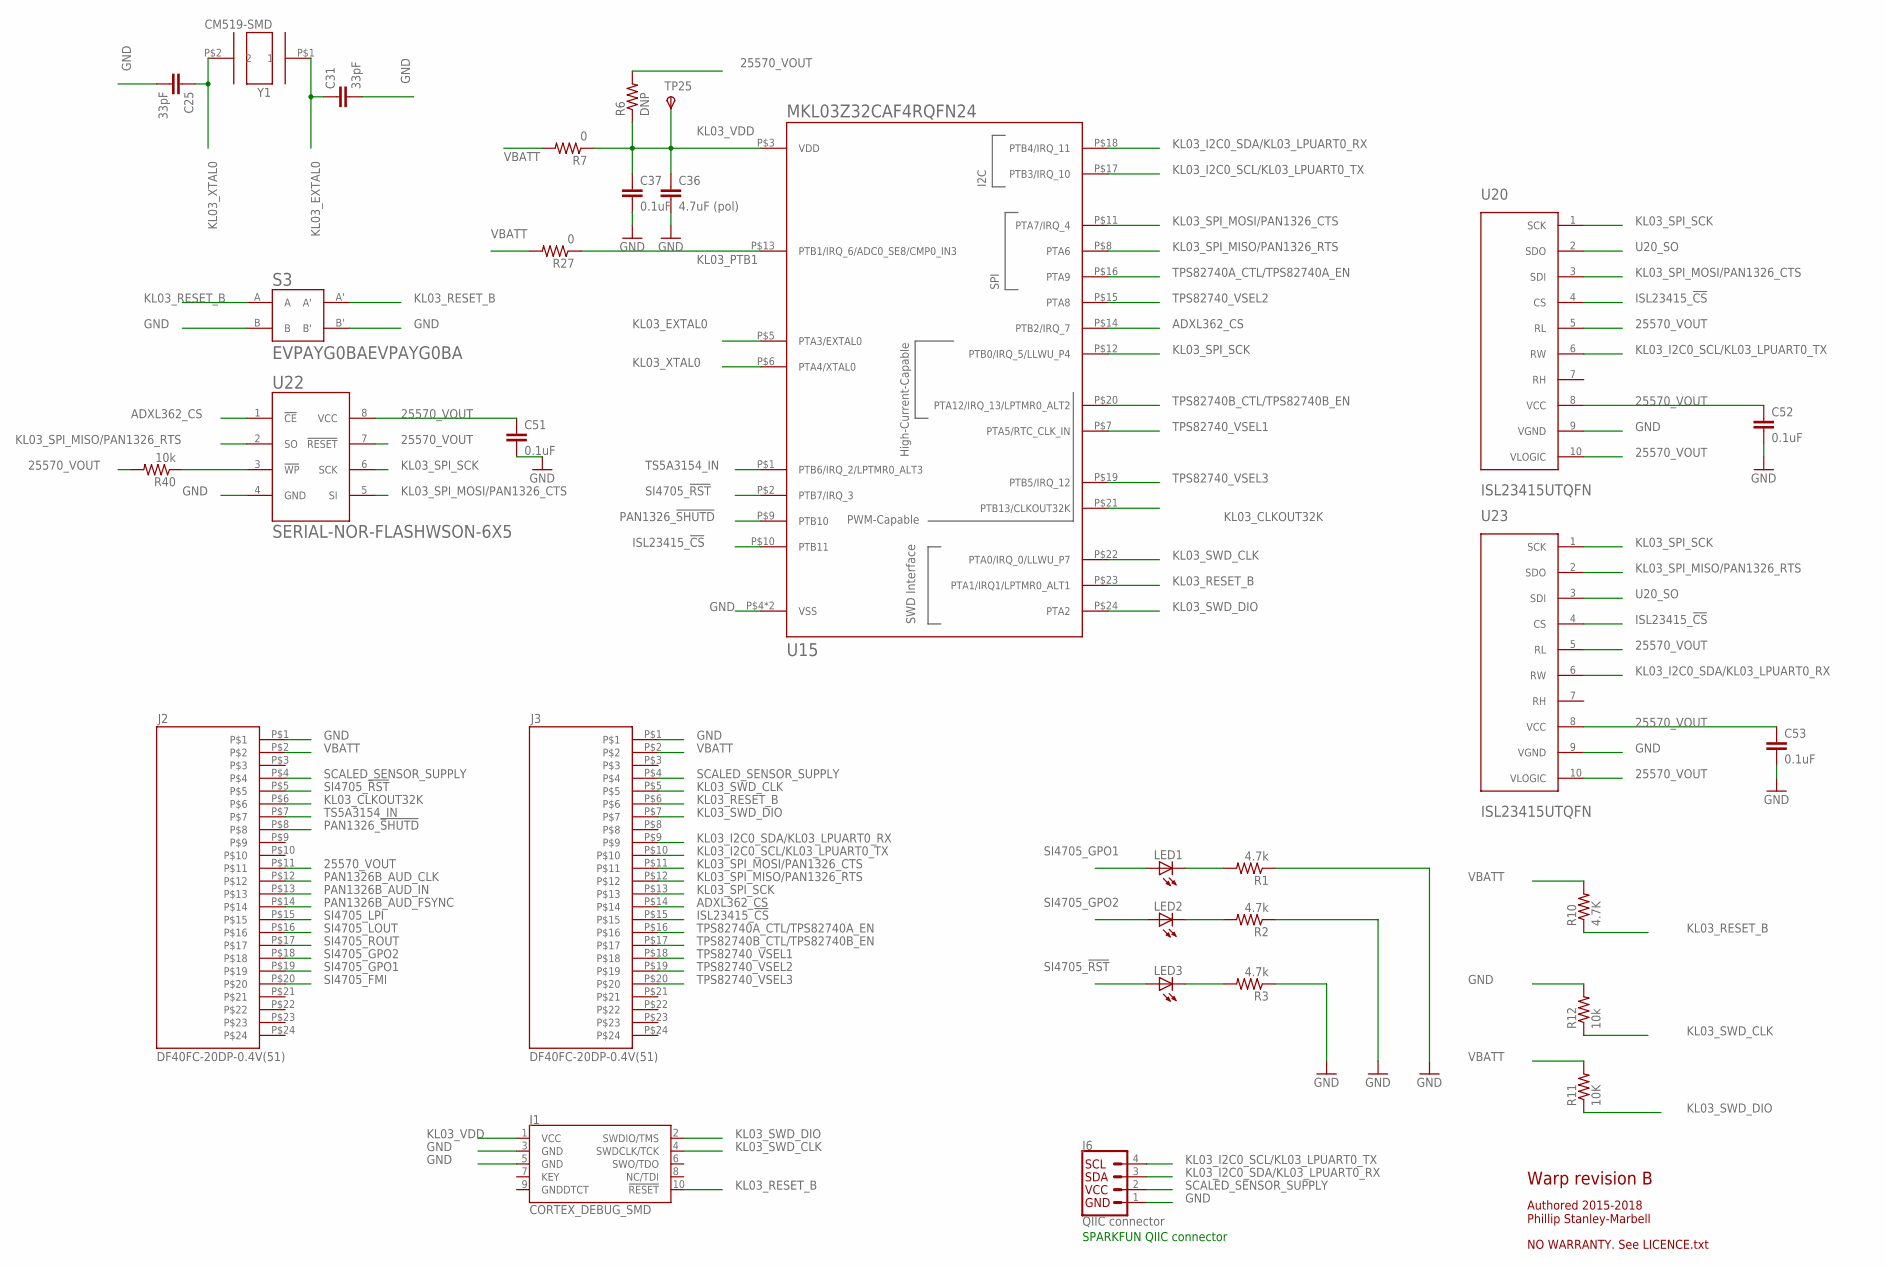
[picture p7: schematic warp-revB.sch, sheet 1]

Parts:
C25, C31: 33pF; 0402-CAP
C36: 4.7uF (pol); 0402-CAP
C37, C51, C52, C53: 0.1uF; 0402-CAP
J1: CORTEX_DEBUG_SMD; SAMTECH_FTSH-105-01
J2, J3: DF40FC-20DP-0.4V(51); DF40C-20DP-0.4V(51)
J6: QIIC connector; 1X04_1MM_RA
LED1, LED2, LED3: LEDSML0603; SML0603
R1, R2, R3: 4.7k; 0402-RES
R6: DNP; 0402-RES
R7, R27: 0; 0402-RES
R10: 4.7K; 0402-RES
R11: 10K; 0402-RES
R12, R40: 10k; 0402-RES
S3: EVPAYG0BAEVPAYG0BA; EVPAYG0BA
TP25: TPSTP06R; TP06R
U15: MKL03Z32CAF4RQFN24; MKL03Z32VFK4R
U20, U23: ISL23415UTQFN; ISL23415
U22: SERIAL-NOR-FLASHWSON-6X5; WSON-6X5
Y1: CM519-SMD; CM519

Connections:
25570_VOUT: C51.1, C52.1, C53.1, J2.P$11, R6.2, R40.2, U20.5 (RL), U20.8 (VCC), U20.10 (VLOGIC), U22.7 (!RESET), U22.8 (VCC), U23.5 (RL), U23.8 (VCC), U23.10 (VLOGIC); also elsewhere on the board
ADXL362_CS: J3.P$14, U15.P$14 (PTB2/IRQ_7), U22.1 (!CE); also elsewhere on the board
GND: C25.2, C31.2, C36.2, C37.2, C51.2, C52.2, C53.2, J1.3 (GND), J1.5 (GND), J2.P$1, J3.P$1, J6.1 (GND), R1.1, R2.1, R3.1, R12.2, S3.B, S3.B', U15.P$4 (VSS), U15.P$PAD (VSS), U20.9 (VGND), U22.4 (GND), U23.9 (VGND); also elsewhere on the board
ISL23415_!CS: J3.P$15, U15.P$10 (PTB11), U20.4 (CS), U23.4 (CS); also elsewhere on the board
KL03_CLKOUT32K: J2.P$6, U15.P$21 (PTB13/CLKOUT32K); also elsewhere on the board
KL03_EXTAL0: C31.1, U15.P$5 (PTA3/EXTAL0), Y1.P$1 (1)
KL03_I2C0_SCL/KL03_LPUART0_TX: J3.P$10, J6.4 (SCL), U15.P$17 (PTB3/IRQ_10), U20.6 (RW); also elsewhere on the board
KL03_I2C0_SDA/KL03_LPUART0_RX: J3.P$9, J6.3 (SDA), U15.P$18 (PTB4/IRQ_11), U23.6 (RW); also elsewhere on the board
KL03_PTB1: R27.1, U15.P$13 (PTB1/IRQ_6/ADC0_SE8/CMP0_IN3)
KL03_RESET_B: J1.10 (!RESET), J3.P$6, R10.1, S3.A, S3.A', U15.P$23 (PTA1/IRQ1/LPTMR0_ALT1)
KL03_SPI_MISO/PAN1326_RTS: J3.P$12, U15.P$8 (PTA6), U22.2 (SO), U23.2 (SDO); also elsewhere on the board
KL03_SPI_MOSI/PAN1326_CTS: J3.P$11, U15.P$11 (PTA7/IRQ_4), U20.3 (SDI), U22.5 (SI); also elsewhere on the board
KL03_SPI_SCK: J3.P$13, U15.P$12 (PTB0/IRQ_5/LLWU_P4), U20.1 (SCK), U22.6 (SCK), U23.1 (SCK); also elsewhere on the board
KL03_SWD_CLK: J1.4 (SWDCLK/TCK), J3.P$5, R12.1, U15.P$22 (PTA0/IRQ_0/LLWU_P7)
KL03_SWD_DIO: J1.2 (SWDIO/TMS), J3.P$7, R11.1, U15.P$24 (PTA2)
KL03_VDD: C36.1, C37.1, J1.1 (VCC), R6.1, R7.1, TP25.TP, U15.P$3 (VDD); also elsewhere on the board
KL03_XTAL0: C25.1, U15.P$6 (PTA4/XTAL0), Y1.P$2 (2)
unnamed: LED1.C, R1.2
unnamed: LED2.C, R2.2
unnamed: LED3.C, R3.2
unnamed: R40.1, U22.3 (!WP)
PAN1326B_AUD_CLK: J2.P$12; also elsewhere on the board
PAN1326B_AUD_FSYNC: J2.P$14; also elsewhere on the board
PAN1326B_AUD_IN: J2.P$13; also elsewhere on the board
PAN1326_!SHUTD: J2.P$8, U15.P$9 (PTB10); also elsewhere on the board
SCALED_SENSOR_SUPPLY: J2.P$4, J3.P$4, J6.2 (VCC); also elsewhere on the board
SI4705_!RST: J2.P$5, LED3.A, U15.P$2 (PTB7/IRQ_3); also elsewhere on the board
SI4705_FMI: J2.P$20; also elsewhere on the board
SI4705_GPO1: J2.P$19, LED1.A; also elsewhere on the board
SI4705_GPO2: J2.P$18, LED2.A; also elsewhere on the board
SI4705_LOUT: J2.P$16; also elsewhere on the board
SI4705_LPI: J2.P$15; also elsewhere on the board
SI4705_ROUT: J2.P$17; also elsewhere on the board
TPS82740A_CTL/TPS82740A_EN: J3.P$16, U15.P$16 (PTA9); also elsewhere on the board
TPS82740B_CTL/TPS82740B_EN: J3.P$17, U15.P$20 (PTA12/IRQ_13/LPTMR0_ALT2); also elsewhere on the board
TPS82740_VSEL1: J3.P$18, U15.P$7 (PTA5/RTC_CLK_IN); also elsewhere on the board
TPS82740_VSEL2: J3.P$19, U15.P$15 (PTA8); also elsewhere on the board
TPS82740_VSEL3: J3.P$20, U15.P$19 (PTB5/IRQ_12); also elsewhere on the board
TS5A3154_IN: J2.P$7, U15.P$1 (PTB6/IRQ_2/LPTMR0_ALT3); also elsewhere on the board
U20_SO: U20.2 (SDO), U23.3 (SDI)
VBATT: J2.P$2, J3.P$2, R7.2, R10.2, R11.2, R27.2; also elsewhere on the board

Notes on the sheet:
SPARKFUN QIIC connector
Warp revision B
Authored 2015-2018 Phillip Stanley-Marbell
NO WARRANTY. See LICENCE.txt

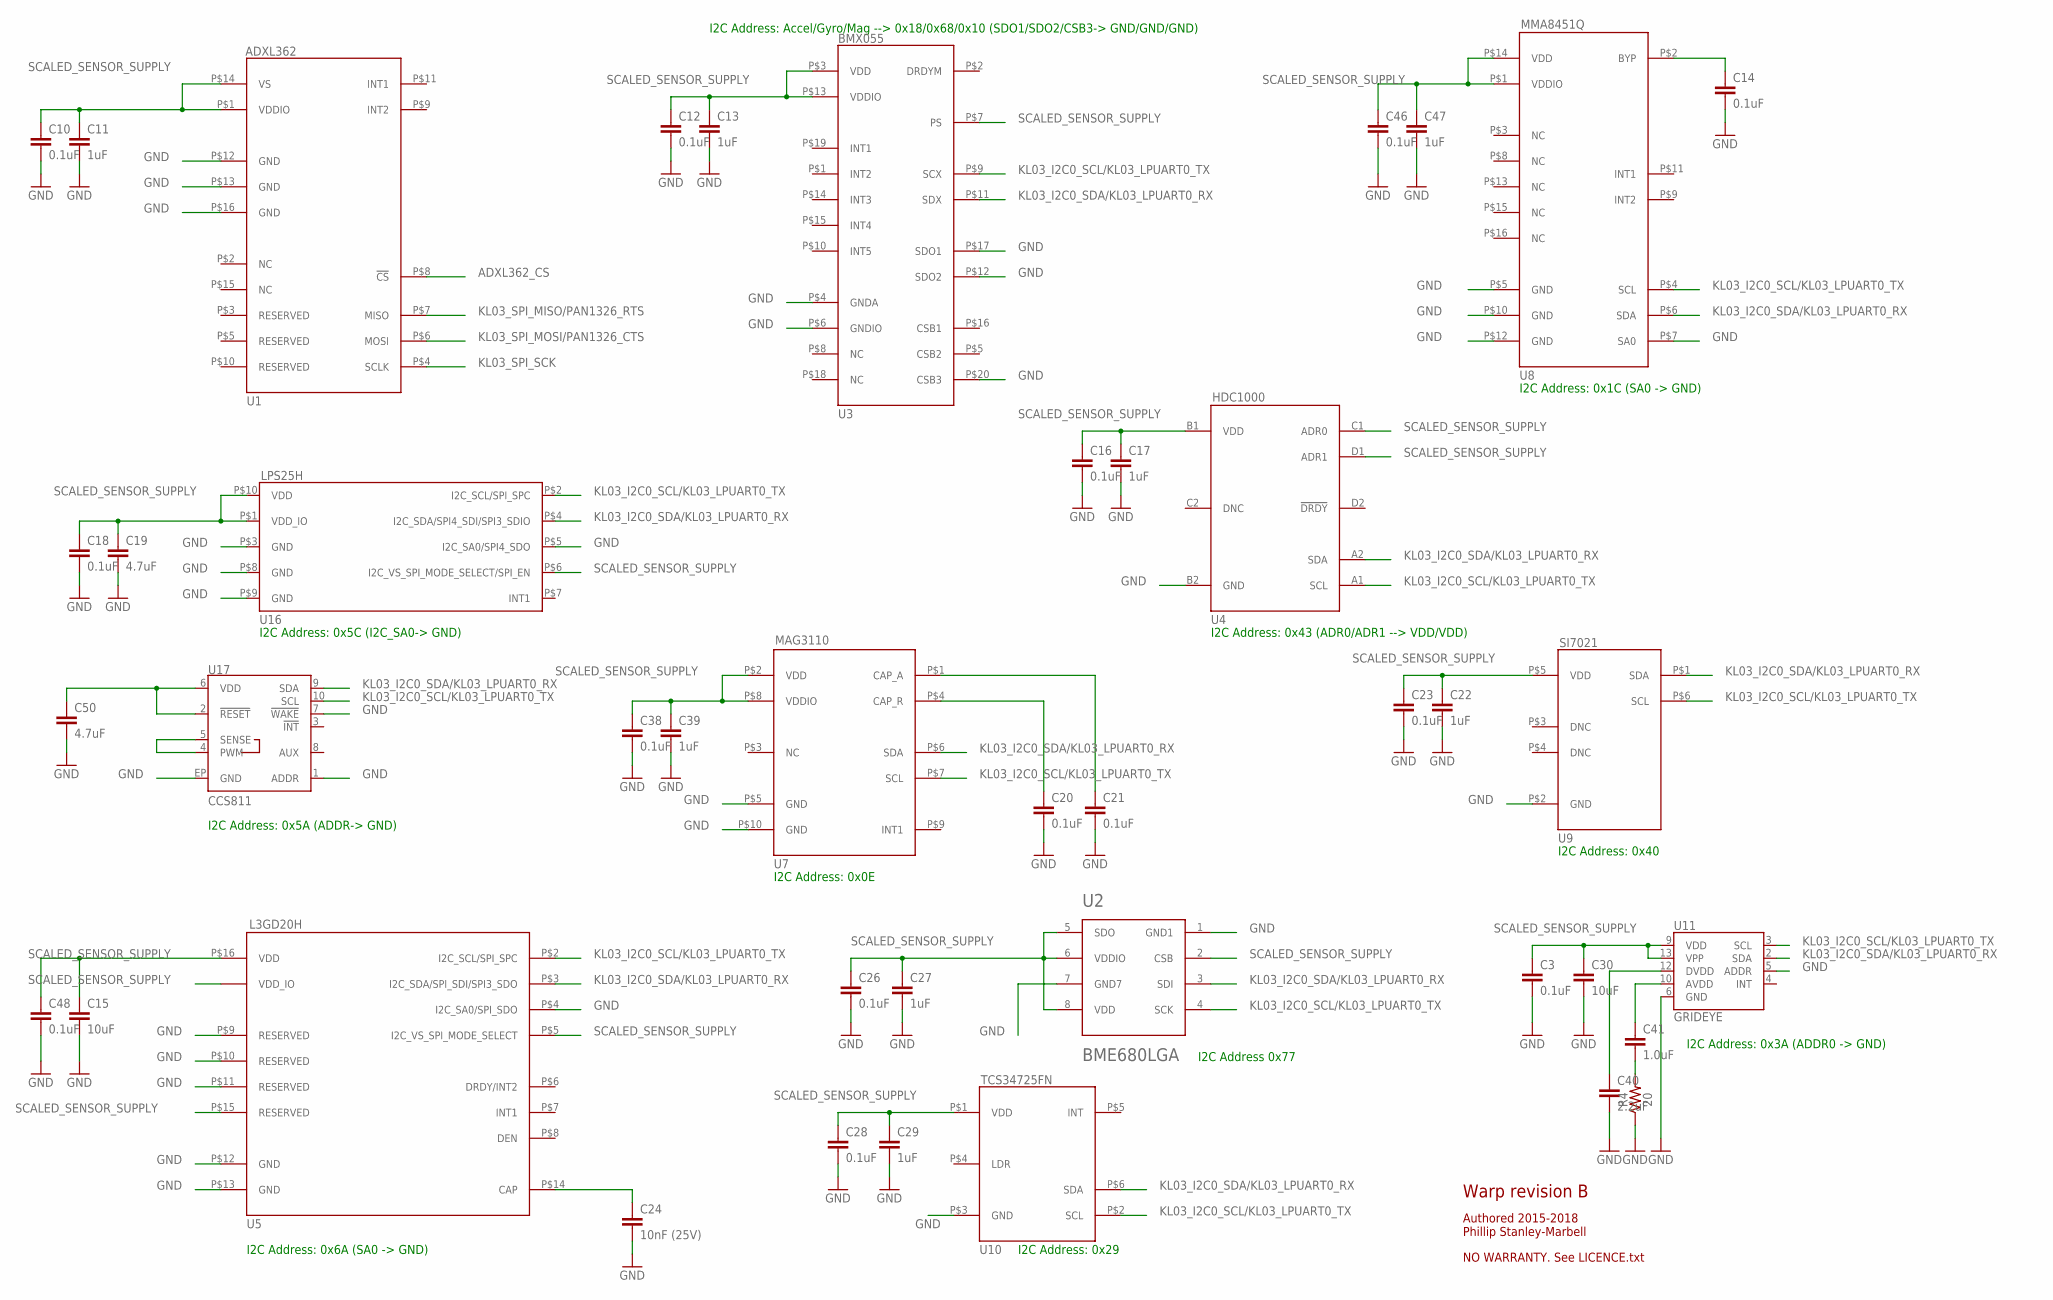
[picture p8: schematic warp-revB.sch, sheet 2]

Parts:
C3, C10, C12, C14, C16, C18, C20, C21, C23, C26, C28, C38, C46, C48: 0.1uF; 0402-CAP
C11, C13, C17, C22, C27, C29, C39, C47: 1uF; 0402-CAP
C15, C30: 10uF; 0402-CAP
C19, C50: 4.7uF; 0402-CAP
C24: 10nF (25V); 0402-CAP
C40: 2.2uF; 0402-CAP
C41: 1.0uF; 0402-CAP
R4: 20; 0402
U1: ADXL362
U2: BME680LGA; BME680
U3: BMX055
U4: HDC1000
U5: L3GD20H
U7: MAG3110
U8: MMA8451Q
U9: SI7021
U10: TCS34725FN; TCS3772
U11: GRIDEYE; GRIDEYE-AMG88
U16: LPS25H
U17: CCS811; LGA10

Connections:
ADXL362_CS: U1.P$8 (!CS); also elsewhere on the board
GND: C3.2, C10.2, C11.2, C12.2, C13.2, C14.2, C15.2, C16.2, C17.2, C18.2, C19.2, C20.2, C21.2, C22.2, C23.2, C24.2, C26.2, C27.2, C28.2, C29.2, C30.2, C38.2, C39.2, C40.2, C46.2, C47.2, C48.2, C50.2, R4.1, U1.P$12 (GND), U1.P$13 (GND), U1.P$16 (GND), U2.1 (GND1), U2.7 (GND7), U3.P$4 (GNDA), U3.P$6 (GNDIO), U3.P$12 (SDO2), U3.P$17 (SDO1), U3.P$20 (CSB3), U4.B2 (GND), U5.P$4 (I2C_SA0/SPI_SDO), U5.P$9 (RESERVED), U5.P$10 (RESERVED), U5.P$11 (RESERVED), U5.P$12 (GND), U5.P$13 (GND), U7.P$5 (GND), U7.P$10 (GND), U8.P$5 (GND), U8.P$7 (SA0), U8.P$10 (GND), U8.P$12 (GND), U9.P$2 (GND), U10.P$3 (GND), U11.5 (ADDR), U11.6 (GND), U16.P$3 (GND), U16.P$5 (I2C_SA0/SPI4_SDO), U16.P$8 (GND), U16.P$9 (GND), U17.1 (ADDR), U17.7 (!WAKE!), U17.EP (GND); also elsewhere on the board
KL03_I2C0_SCL/KL03_LPUART0_TX: U2.4 (SCK), U3.P$9 (SCX), U4.A1 (SCL), U5.P$2 (I2C_SCL/SPI_SPC), U7.P$7 (SCL), U8.P$4 (SCL), U9.P$6 (SCL), U10.P$2 (SCL), U11.3 (SCL), U16.P$2 (I2C_SCL/SPI_SPC), U17.10 (SCL); also elsewhere on the board
KL03_I2C0_SDA/KL03_LPUART0_RX: U2.3 (SDI), U3.P$11 (SDX), U4.A2 (SDA), U5.P$3 (I2C_SDA/SPI_SDI/SPI3_SDO), U7.P$6 (SDA), U8.P$6 (SDA), U9.P$1 (SDA), U10.P$6 (SDA), U11.2 (SDA), U16.P$4 (I2C_SDA/SPI4_SDI/SPI3_SDIO), U17.9 (SDA); also elsewhere on the board
KL03_SPI_MISO/PAN1326_RTS: U1.P$7 (MISO); also elsewhere on the board
KL03_SPI_MOSI/PAN1326_CTS: U1.P$6 (MOSI); also elsewhere on the board
KL03_SPI_SCK: U1.P$4 (SCLK); also elsewhere on the board
unnamed: U17.4 (PWM), U17.5 (SENSE)
unnamed: C41.2, R4.2
unnamed: C40.1, U11.12 (DVDD)
unnamed: C41.1, U11.10 (AVDD)
unnamed: C14.1, U8.P$2 (BYP)
unnamed: C21.1, U7.P$1 (CAP_A)
unnamed: C20.1, U7.P$4 (CAP_R)
unnamed: C24.1, U5.P$14 (CAP)
SCALED_SENSOR_SUPPLY: C3.1, C10.1, C11.1, C12.1, C13.1, C15.1, C16.1, C17.1, C18.1, C19.1, C22.1, C23.1, C26.1, C27.1, C28.1, C29.1, C30.1, C38.1, C39.1, C46.1, C47.1, C48.1, C50.1, U1.P$1 (VDDIO), U1.P$14 (VS), U2.2 (CSB), U2.5 (SDO), U2.6 (VDDIO), U2.8 (VDD), U3.P$3 (VDD), U3.P$7 (PS), U3.P$13 (VDDIO), U4.B1 (VDD), U4.C1 (ADR0), U4.D1 (ADR1), U5.P$1 (VDD_IO), U5.P$5 (I2C_VS_SPI_MODE_SELECT), U5.P$15 (RESERVED), U5.P$16 (VDD), U7.P$2 (VDD), U7.P$8 (VDDIO), U8.P$1 (VDDIO), U8.P$14 (VDD), U9.P$5 (VDD), U10.P$1 (VDD), U11.9 (VDD), U11.13 (VPP), U16.P$1 (VDD_IO), U16.P$6 (I2C_VS_SPI_MODE_SELECT/SPI_EN), U16.P$10 (VDD), U17.2 (!RESET!), U17.6 (VDD); also elsewhere on the board

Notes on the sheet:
I2C Address: 0x1C (SA0 -> GND)
I2C Address: Accel/Gyro/Mag --> 0x18/0x68/0x10 (SDO1/SDO2/CSB3-> GND/GND/GND)
I2C Address: 0x43 (ADR0/ADR1 --> VDD/VDD)
I2C Address: 0x5C (I2C_SA0-> GND)
I2C Address: 0x0E
I2C Address: 0x40
I2C Address: 0x6A (SA0 -> GND)
I2C Address 0x77
I2C Address: 0x29
I2C Address: 0x3A (ADDR0 -> GND)
I2C Address: 0x5A (ADDR-> GND)
Warp revision B
Authored 2015-2018 Phillip Stanley-Marbell
NO WARRANTY. See LICENCE.txt

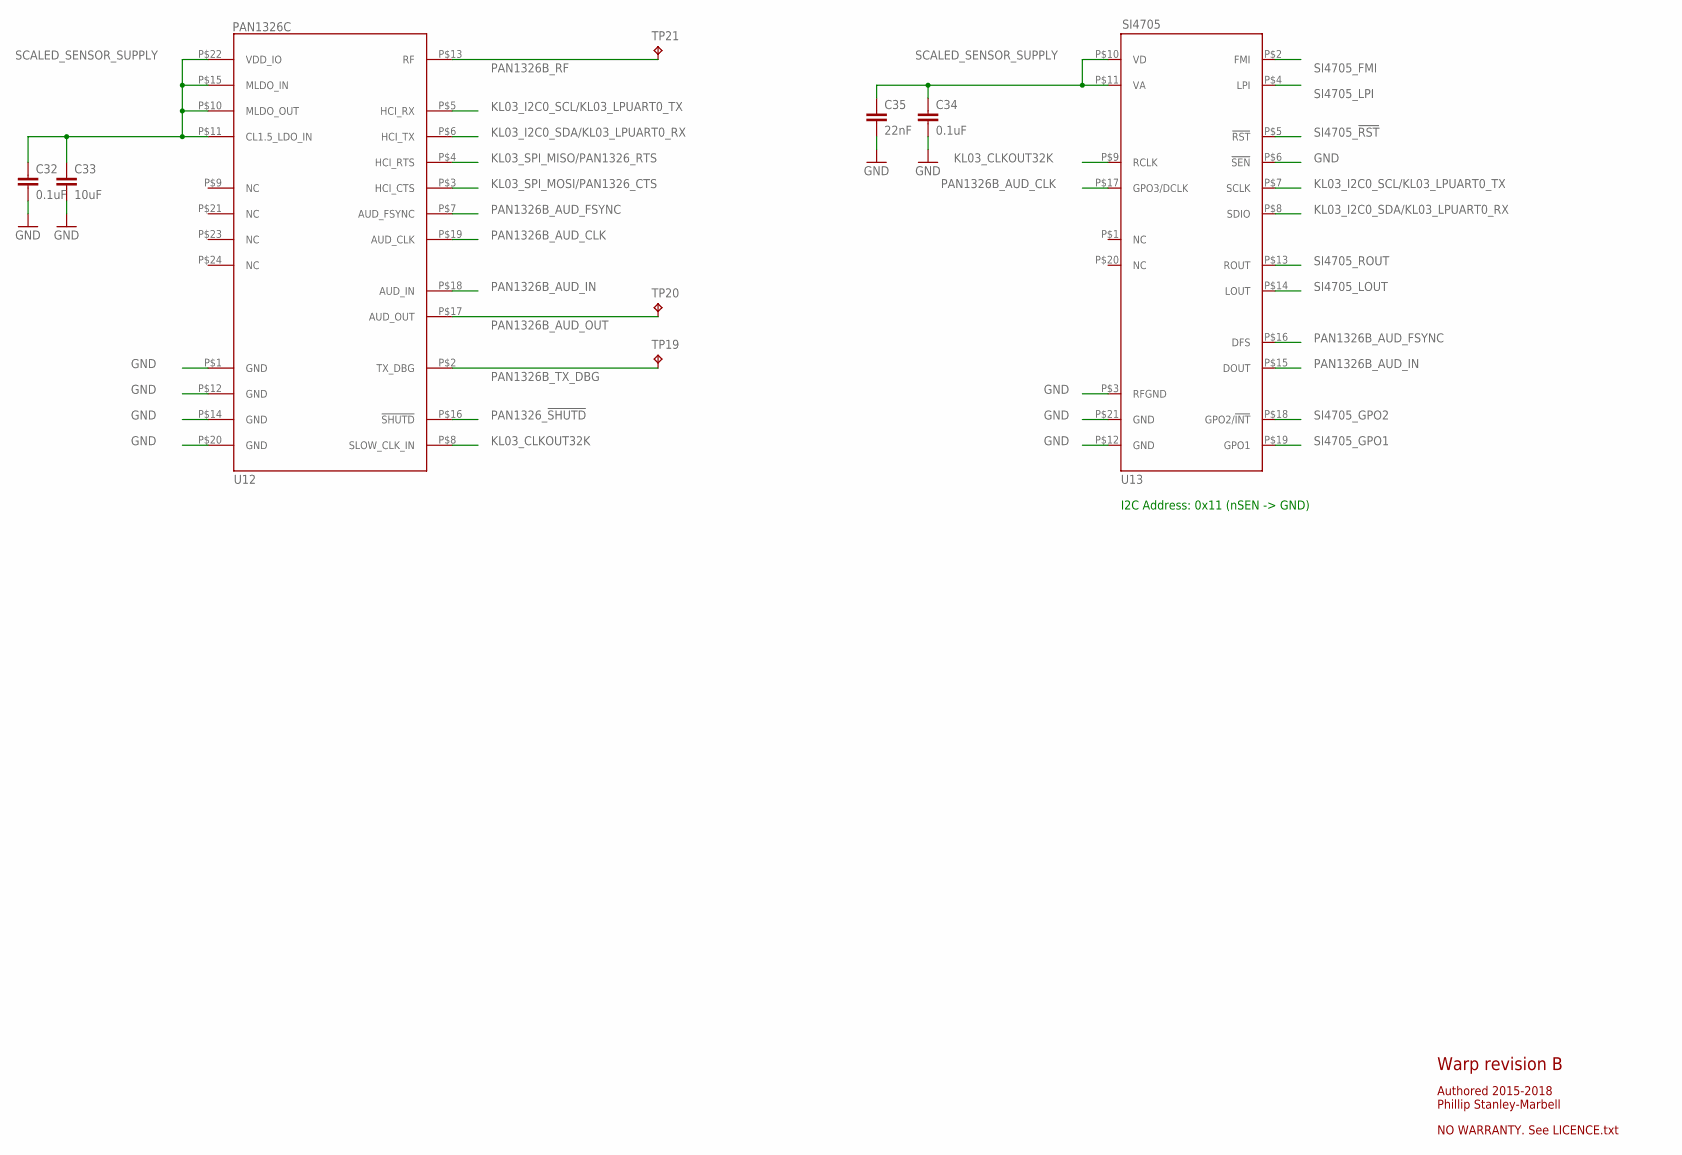
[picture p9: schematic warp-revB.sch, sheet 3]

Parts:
C32, C34: 0.1uF; 0402-CAP
C33: 10uF; 0402-CAP
C35: 22nF; 0402-CAP
TP19, TP20, TP21: TPTP06R; TP06R
U12: PAN1326C; PAN1326B
U13: SI4705

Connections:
GND: C32.2, C33.2, C34.2, C35.2, U12.P$1 (GND), U12.P$12 (GND), U12.P$14 (GND), U12.P$20 (GND), U13.P$3 (RFGND), U13.P$6 (!SEN), U13.P$12 (GND), U13.P$21 (GND); also elsewhere on the board
KL03_CLKOUT32K: U12.P$8 (SLOW_CLK_IN), U13.P$9 (RCLK); also elsewhere on the board
KL03_I2C0_SCL/KL03_LPUART0_TX: U12.P$5 (HCI_RX), U13.P$7 (SCLK); also elsewhere on the board
KL03_I2C0_SDA/KL03_LPUART0_RX: U12.P$6 (HCI_TX), U13.P$8 (SDIO); also elsewhere on the board
KL03_SPI_MISO/PAN1326_RTS: U12.P$4 (HCI_RTS); also elsewhere on the board
KL03_SPI_MOSI/PAN1326_CTS: U12.P$3 (HCI_CTS); also elsewhere on the board
PAN1326B_AUD_CLK: U12.P$19 (AUD_CLK), U13.P$17 (GPO3/DCLK); also elsewhere on the board
PAN1326B_AUD_FSYNC: U12.P$7 (AUD_FSYNC), U13.P$16 (DFS); also elsewhere on the board
PAN1326B_AUD_IN: U12.P$18 (AUD_IN), U13.P$15 (DOUT); also elsewhere on the board
PAN1326B_AUD_OUT: TP20.TP, U12.P$17 (AUD_OUT)
PAN1326B_RF: TP21.TP, U12.P$13 (RF)
PAN1326B_TX_DBG: TP19.TP, U12.P$2 (TX_DBG)
PAN1326_!SHUTD: U12.P$16 (!SHUTD); also elsewhere on the board
SCALED_SENSOR_SUPPLY: C32.1, C33.1, C34.1, C35.1, U12.P$10 (MLDO_OUT), U12.P$11 (CL1.5_LDO_IN), U12.P$15 (MLDO_IN), U12.P$22 (VDD_IO), U13.P$10 (VD), U13.P$11 (VA); also elsewhere on the board
SI4705_!RST: U13.P$5 (!RST); also elsewhere on the board
SI4705_FMI: U13.P$2 (FMI); also elsewhere on the board
SI4705_GPO1: U13.P$19 (GPO1); also elsewhere on the board
SI4705_GPO2: U13.P$18 (GPO2/!INT); also elsewhere on the board
SI4705_LOUT: U13.P$14 (LOUT); also elsewhere on the board
SI4705_LPI: U13.P$4 (LPI); also elsewhere on the board
SI4705_ROUT: U13.P$13 (ROUT); also elsewhere on the board

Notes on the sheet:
I2C Address: 0x11 (nSEN -> GND)
Warp revision B
Authored 2015-2018 Phillip Stanley-Marbell
NO WARRANTY. See LICENCE.txt

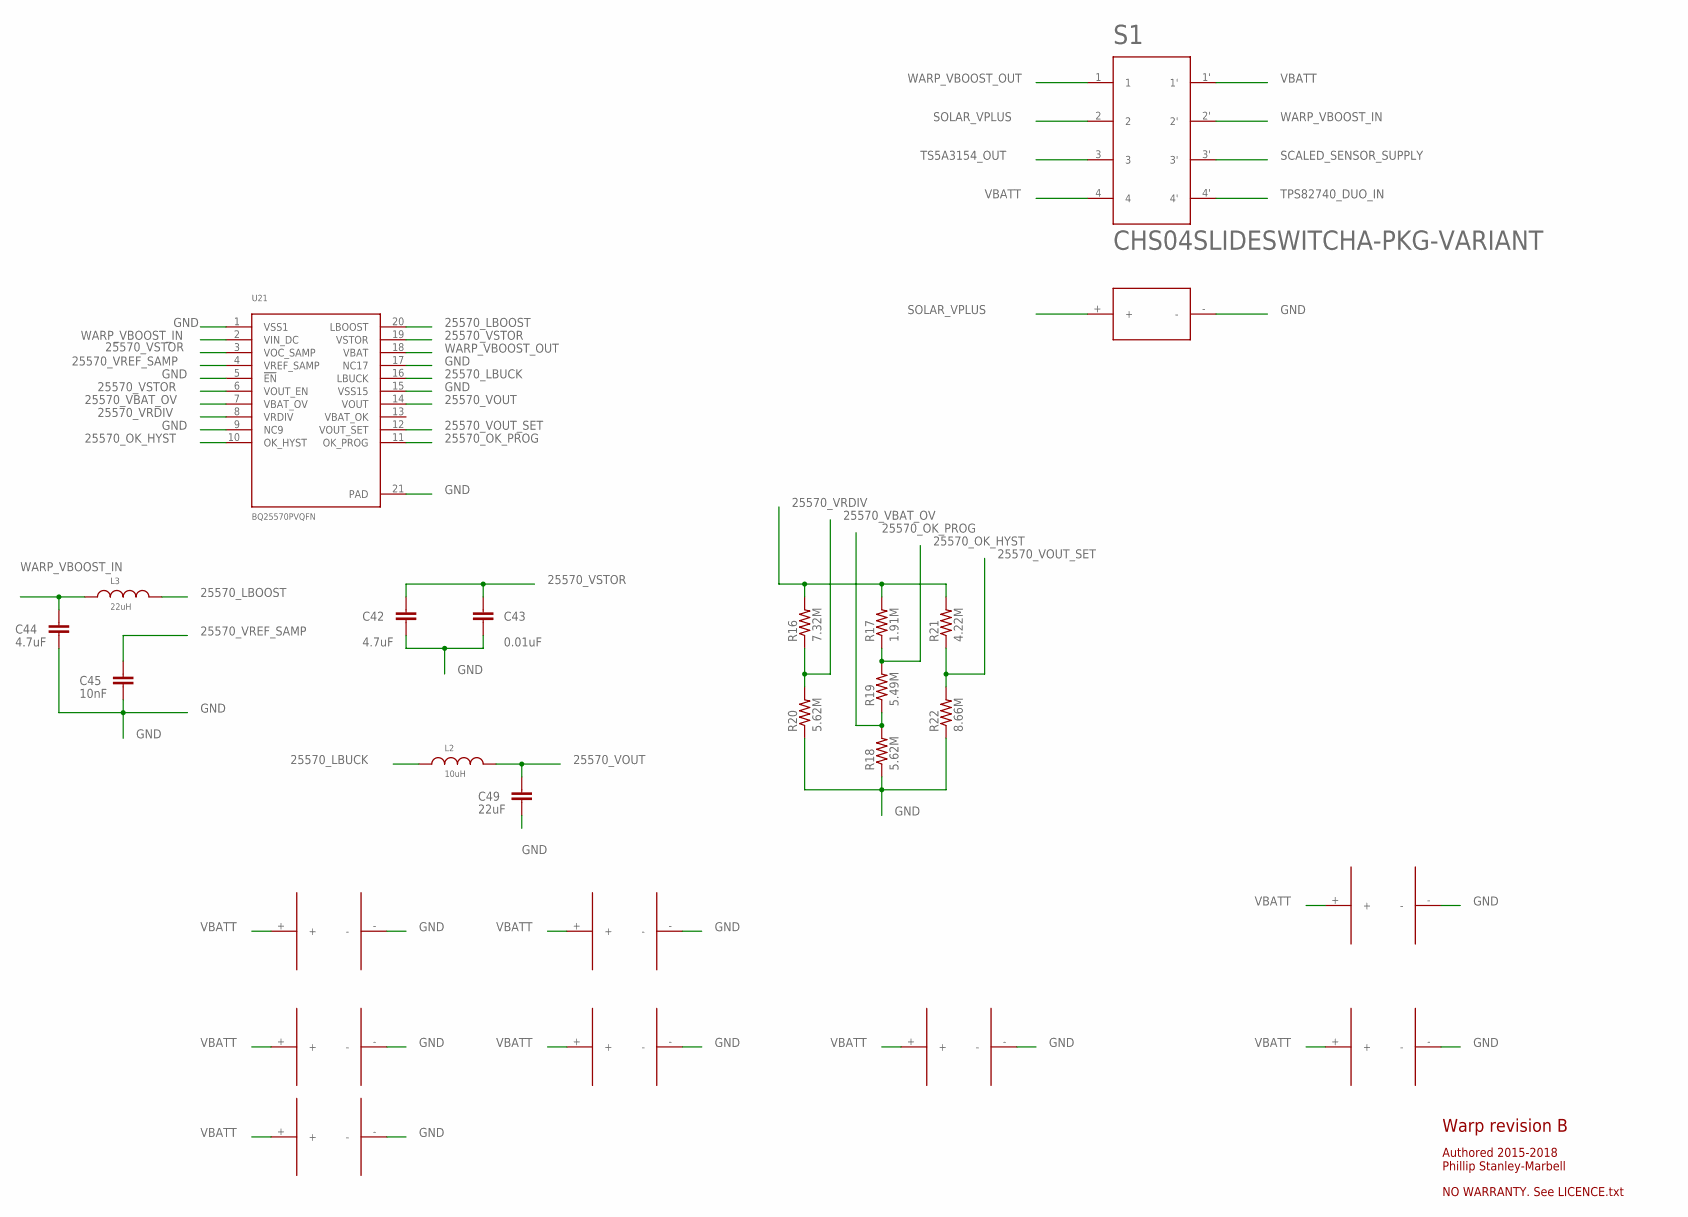
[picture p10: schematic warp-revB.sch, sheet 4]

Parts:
C1, C2, C4, C5, C6, C7, C8, C9: XH414HGIV01E
C42, C44: 4.7uF; 0402-CAP
C43: 0.01uF; 0402-CAP
C45: 10nF; 0402-CAP
C49: 22uF; 0603-CAP
D1: KXOB22-04X3F
L2: 10uH; WE-TPC_2811/2813_OLD
L3: 22uH; WE-TPC_3816
R16: 7.32M; 0402-RES
R17: 1.91M; 0402-RES
R18, R20: 5.62M; 0402-RES
R19: 5.49M; 0402-RES
R21: 4.22M; 0402-RES
R22: 8.66M; 0402-RES
S1: CHS04SLIDESWITCHA-PKG-VARIANT; CHS04SLIDESWITCH
U21: BQ25570PVQFN; BQ25570

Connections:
25570_LBOOST: L3.2, U21.20 (LBOOST)
25570_LBUCK: L2.1, U21.16 (LBUCK)
25570_OK_HYST: R17.1, R19.2, U21.10 (OK_HYST)
25570_OK_PROG: R18.2, R19.1, U21.11 (OK_PROG)
25570_VBAT_OV: R16.1, R20.2, U21.7 (VBAT_OV)
25570_VOUT: C49.1, L2.2, U21.14 (VOUT); also elsewhere on the board
25570_VOUT_SET: R21.1, R22.2, U21.12 (VOUT_SET)
25570_VRDIV: R16.2, R17.2, R21.2, U21.8 (VRDIV)
25570_VREF_SAMP: C45.1, U21.4 (VREF_SAMP)
25570_VSTOR: C42.1, C43.1, U21.3 (VOC_SAMP), U21.6 (VOUT_EN), U21.19 (VSTOR)
GND: C1.-, C2.-, C4.-, C5.-, C6.-, C7.-, C8.-, C9.-, C42.2, C43.2, C44.2, C45.2, C49.2, D1.-, R18.1, R20.1, R22.1, U21.1 (VSS1), U21.5 (!EN), U21.9 (NC9), U21.15 (VSS15), U21.17 (NC17), U21.21 (PAD); also elsewhere on the board
SCALED_SENSOR_SUPPLY: S1.3'; also elsewhere on the board
SOLAR_VPLUS: D1.+, S1.2
TPS82740_DUO_IN: S1.4'; also elsewhere on the board
TS5A3154_OUT: S1.3; also elsewhere on the board
VBATT: C1.+, C2.+, C4.+, C5.+, C6.+, C7.+, C8.+, C9.+, S1.1', S1.4; also elsewhere on the board
WARP_VBOOST_IN: C44.1, L3.1, S1.2', U21.2 (VIN_DC); also elsewhere on the board
WARP_VBOOST_OUT: S1.1, U21.18 (VBAT)

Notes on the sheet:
Warp revision B
Authored 2015-2018 Phillip Stanley-Marbell
NO WARRANTY. See LICENCE.txt

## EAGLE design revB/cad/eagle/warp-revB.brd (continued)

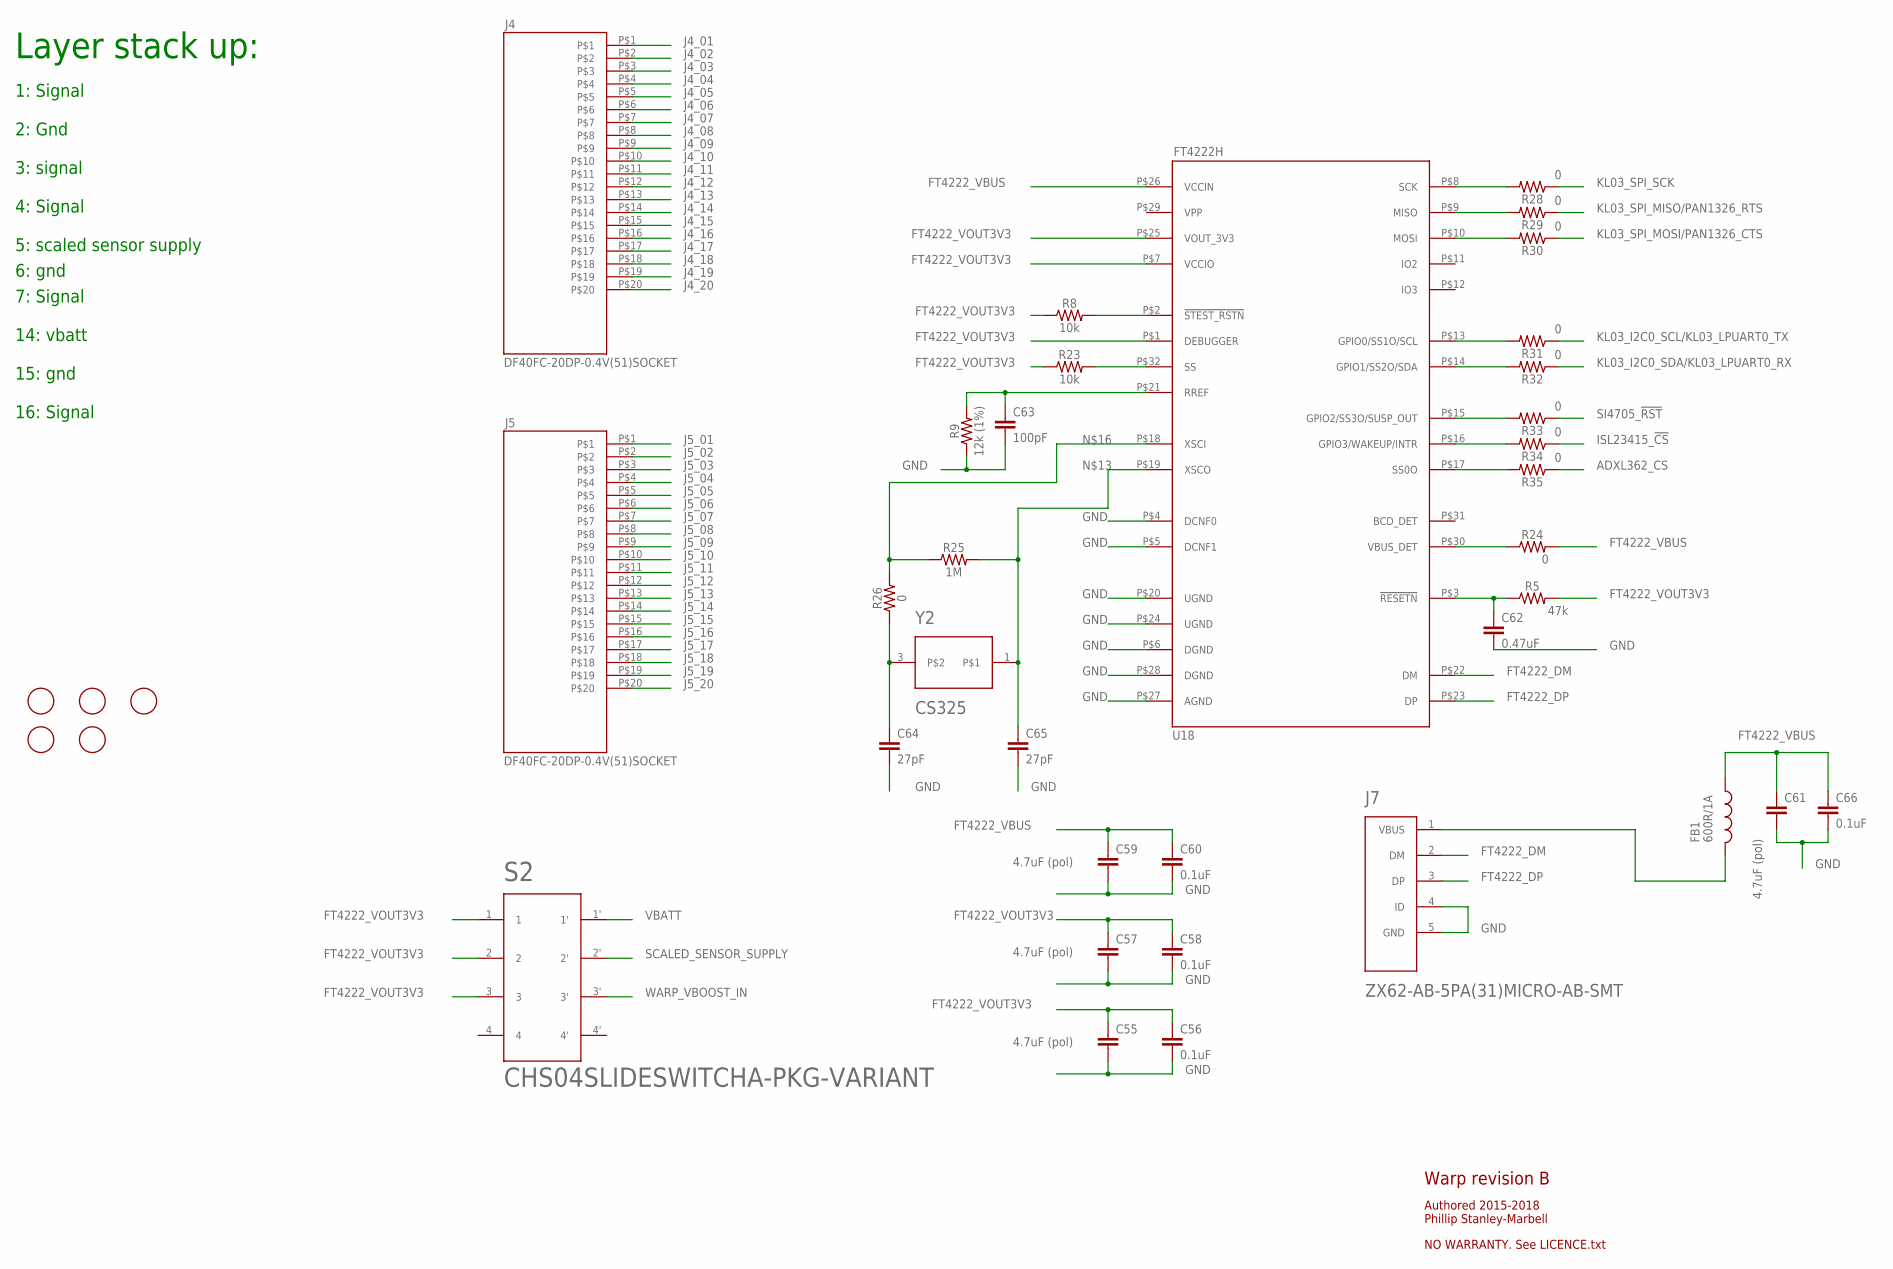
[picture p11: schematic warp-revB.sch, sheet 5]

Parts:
C55, C57, C59, C61: 4.7uF (pol); 0402-CAP
C56, C58, C60, C66: 0.1uF; 0402-CAP
C62: 0.47uF; 0402-CAP
C63: 100pF; 0402-CAP
C64, C65: 27pF; 0402-CAP
FB1: 600R/1A; 0603
FD1, FD2, FD3, FD4, FD5: FIDUCIAL; FIDUCIAL_1MM
J4, J5: DF40FC-20DP-0.4V(51)SOCKET; DF40C-20DP-0.4V(51)
J7: ZX62-AB-5PA(31)MICRO-AB-SMT; ZX62-AB-5PA(31)
R5: 47k; 0402
R8, R23: 10k; 0402
R9: 12k (1%); 0402
R24, R26, R28, R29, R30, R31, R32, R33, R34, R35: 0; 0402
R25: 1M; 0402
S2: CHS04SLIDESWITCHA-PKG-VARIANT; CHS04SLIDESWITCH
U18: FT4222H
Y2: CS325

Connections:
ADXL362_CS: R35.1; also elsewhere on the board
FT4222_DM: J7.2 (DM), U18.P$22 (DM)
FT4222_DP: J7.3 (DP), U18.P$23 (DP)
FT4222_VBUS: C59.1, C60.1, C61.1, C66.1, FB1.1, R24.2, U18.P$26 (VCCIN)
FT4222_VOUT3V3: C55.1, C56.1, C57.1, C58.1, R5.2, R8.1, R23.1, S2.1, S2.2, S2.3, U18.P$1 (DEBUGGER), U18.P$7 (VCCIO), U18.P$25 (VOUT_3V3); also elsewhere on the board
GND: C55.2, C56.2, C57.2, C58.2, C59.2, C60.2, C61.2, C62.2, C63.2, C64.2, C65.2, C66.2, J7.4 (ID), J7.5 (GND), R9.1, U18.P$4 (DCNF0), U18.P$5 (DCNF1), U18.P$6 (DGND), U18.P$20 (UGND), U18.P$24 (UGND), U18.P$27 (AGND), U18.P$28 (DGND); also elsewhere on the board
ISL23415_!CS: R34.1; also elsewhere on the board
J4_01: J4.P$1
J4_02: J4.P$2
J4_03: J4.P$3
J4_04: J4.P$4
J4_05: J4.P$5
J4_06: J4.P$6
J4_07: J4.P$7
J4_08: J4.P$8
J4_09: J4.P$9
J4_10: J4.P$10
J4_11: J4.P$11
J4_12: J4.P$12
J4_13: J4.P$13
J4_14: J4.P$14
J4_15: J4.P$15
J4_16: J4.P$16
J4_17: J4.P$17
J4_18: J4.P$18
J4_19: J4.P$19
J4_20: J4.P$20
J5_01: J5.P$1
J5_02: J5.P$2
J5_03: J5.P$3
J5_04: J5.P$4
J5_05: J5.P$5
J5_06: J5.P$6
J5_07: J5.P$7
J5_08: J5.P$8
J5_09: J5.P$9
J5_10: J5.P$10
J5_11: J5.P$11
J5_12: J5.P$12
J5_13: J5.P$13
J5_14: J5.P$14
J5_15: J5.P$15
J5_16: J5.P$16
J5_17: J5.P$17
J5_18: J5.P$18
J5_19: J5.P$19
J5_20: J5.P$20
KL03_I2C0_SCL/KL03_LPUART0_TX: R31.1; also elsewhere on the board
KL03_I2C0_SDA/KL03_LPUART0_RX: R32.1; also elsewhere on the board
KL03_SPI_MISO/PAN1326_RTS: R29.1; also elsewhere on the board
KL03_SPI_MOSI/PAN1326_CTS: R30.1; also elsewhere on the board
KL03_SPI_SCK: R28.1; also elsewhere on the board
unnamed: R8.2, U18.P$2 (!STEST_RSTN)
unnamed: C62.1, R5.1, U18.P$3 (!RESETN)
unnamed: C63.1, R9.2, U18.P$21 (RREF)
unnamed: FB1.2, J7.1 (VBUS)
unnamed: C65.1, R25.2, U18.P$19 (XSCO), Y2.1
unnamed: R25.1, R26.2, U18.P$18 (XSCI)
unnamed: C64.1, R26.1, Y2.3
unnamed: R28.2, U18.P$8 (SCK)
unnamed: R29.2, U18.P$9 (MISO)
unnamed: R30.2, U18.P$10 (MOSI)
unnamed: R31.2, U18.P$13 (GPIO0/SS1O/SCL)
unnamed: R24.1, U18.P$30 (VBUS_DET)
unnamed: R32.2, U18.P$14 (GPIO1/SS2O/SDA)
unnamed: R33.2, U18.P$15 (GPIO2/SS3O/SUSP_OUT)
unnamed: R34.2, U18.P$16 (GPIO3/WAKEUP/INTR)
unnamed: R35.2, U18.P$17 (SS0O)
unnamed: R23.2, U18.P$32 (SS)
SCALED_SENSOR_SUPPLY: S2.2'; also elsewhere on the board
SI4705_!RST: R33.1; also elsewhere on the board
VBATT: S2.1'; also elsewhere on the board
VPP: U18.P$29 (VPP)
WARP_VBOOST_IN: S2.3'; also elsewhere on the board

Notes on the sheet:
Layer stack up:
1: Signal
2: Gnd
3: signal
14: vbatt
15: gnd
16: Signal
4: Signal
5: scaled sensor supply
6: gnd
7: Signal
Warp revision B
Authored 2015-2018 Phillip Stanley-Marbell
NO WARRANTY. See LICENCE.txt

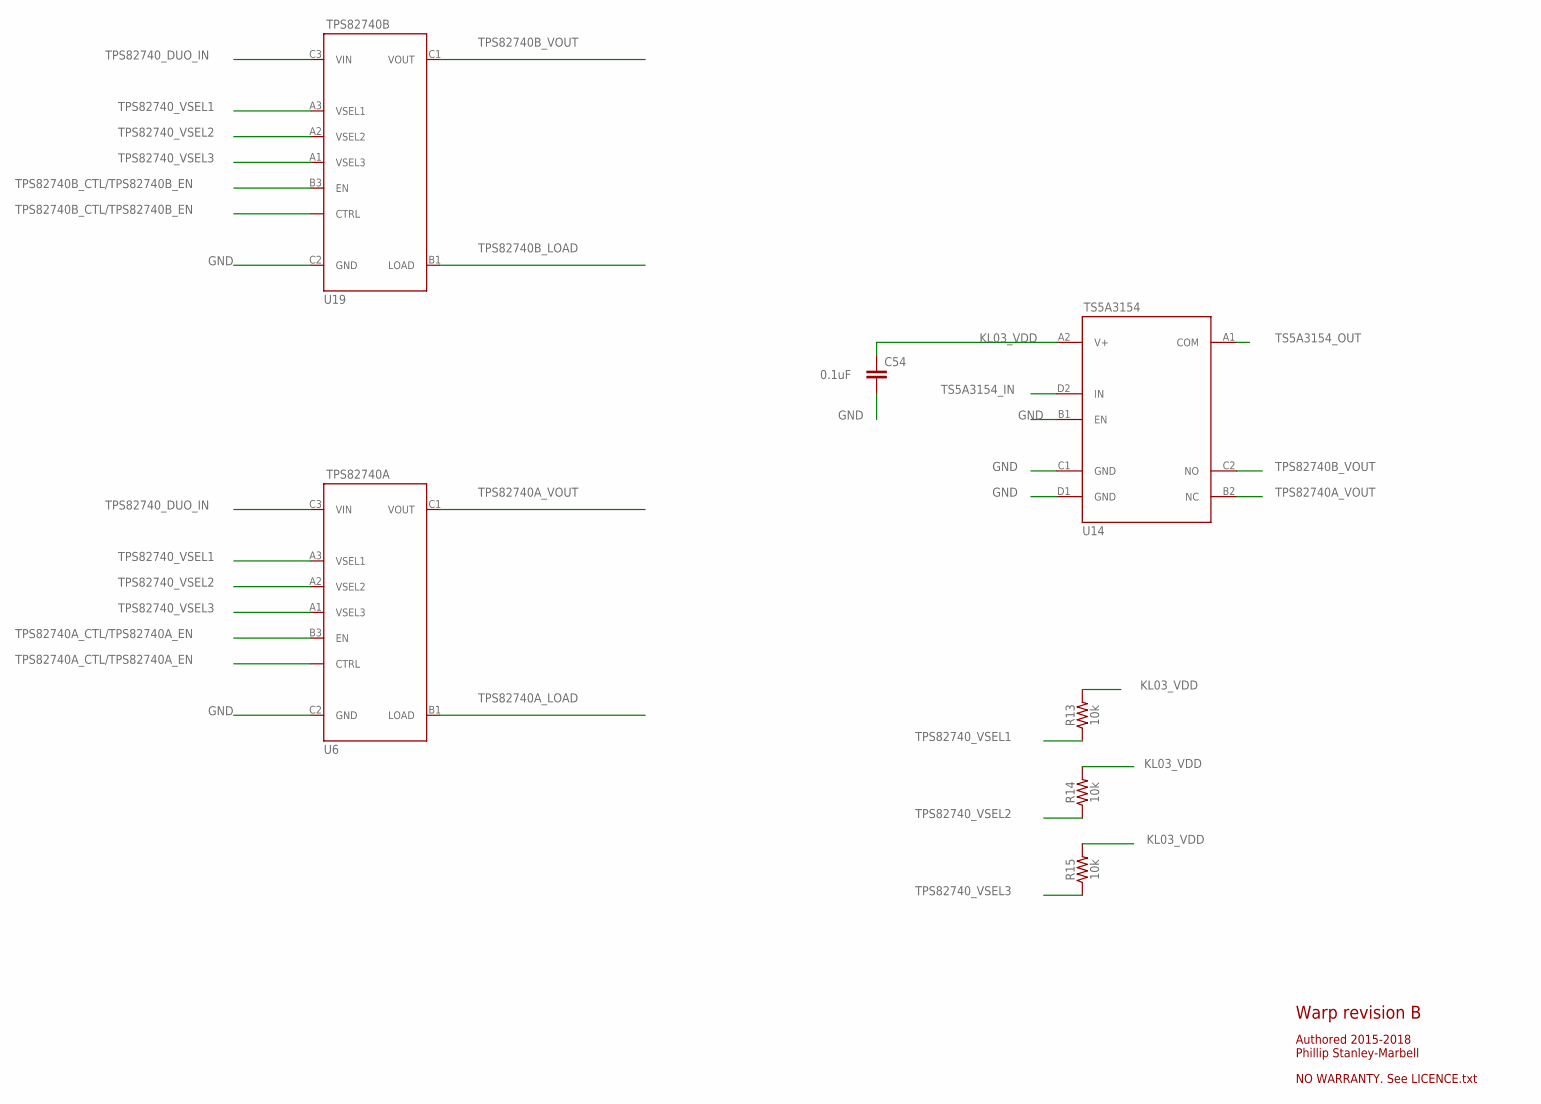
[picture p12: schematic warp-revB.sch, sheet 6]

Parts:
C54: 0.1uF; 0402-CAP
R13, R14, R15: 10k; 0402
U6: TPS82740A; TPS82740
U14: TS5A3154
U19: TPS82740B; TPS82740

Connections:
GND: C54.2, U6.C2 (GND), U14.B1 (EN), U14.C1 (GND), U14.D1 (GND), U19.C2 (GND); also elsewhere on the board
KL03_VDD: C54.1, R13.2, R14.2, R15.2, U14.A2 (V+); also elsewhere on the board
TPS82740A_CTL/TPS82740A_EN: U6.B2 (CTRL), U6.B3 (EN); also elsewhere on the board
TPS82740A_LOAD: U6.B1 (LOAD)
TPS82740A_VOUT: U6.C1 (VOUT), U14.B2 (NC)
TPS82740B_CTL/TPS82740B_EN: U19.B2 (CTRL), U19.B3 (EN); also elsewhere on the board
TPS82740B_LOAD: U19.B1 (LOAD)
TPS82740B_VOUT: U14.C2 (NO), U19.C1 (VOUT)
TPS82740_DUO_IN: U6.C3 (VIN), U19.C3 (VIN); also elsewhere on the board
TPS82740_VSEL1: R13.1, U6.A3 (VSEL1), U19.A3 (VSEL1); also elsewhere on the board
TPS82740_VSEL2: R14.1, U6.A2 (VSEL2), U19.A2 (VSEL2); also elsewhere on the board
TPS82740_VSEL3: R15.1, U6.A1 (VSEL3), U19.A1 (VSEL3); also elsewhere on the board
TS5A3154_IN: U14.D2 (IN); also elsewhere on the board
TS5A3154_OUT: U14.A1 (COM); also elsewhere on the board

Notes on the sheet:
Warp revision B
Authored 2015-2018 Phillip Stanley-Marbell
NO WARRANTY. See LICENCE.txt

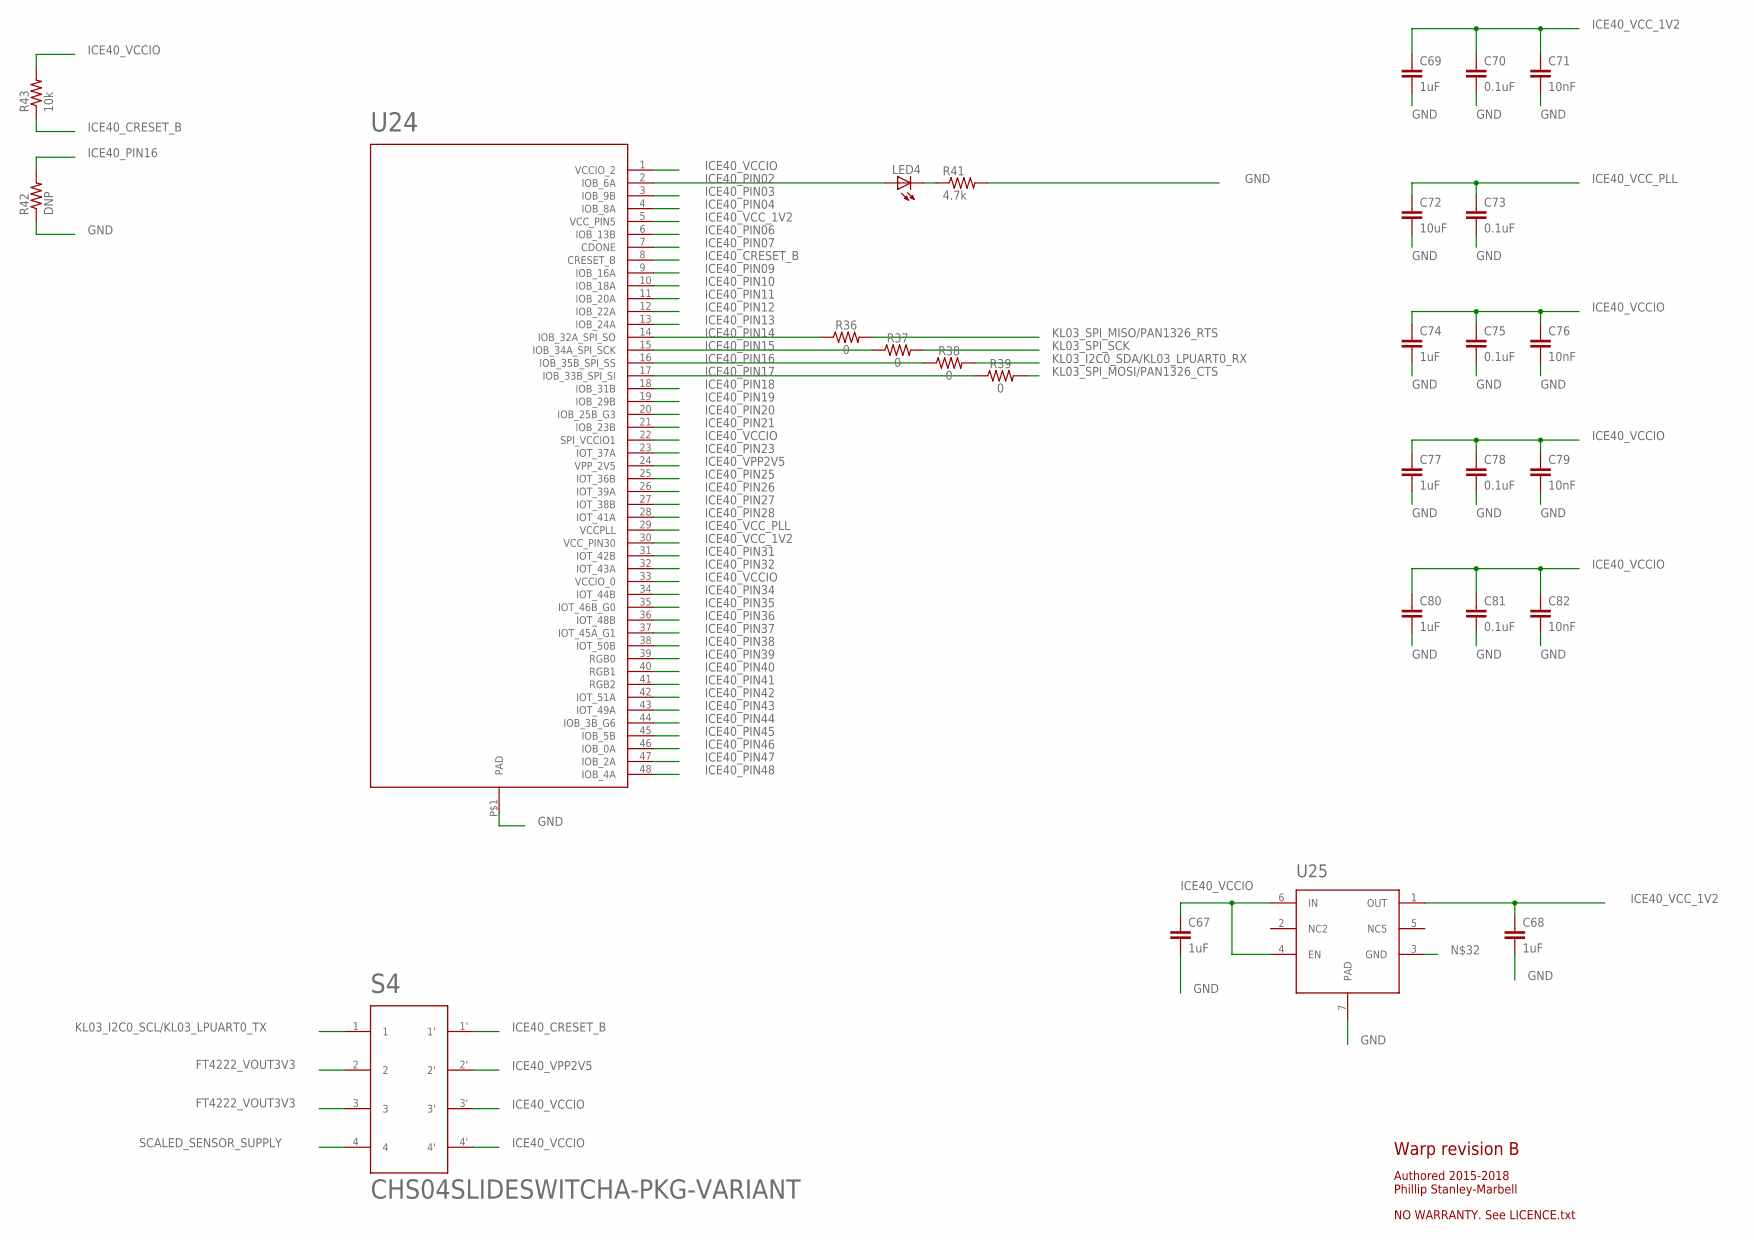
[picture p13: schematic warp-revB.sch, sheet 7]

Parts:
C67, C68, C69, C74, C77, C80: 1uF; 0402-CAP
C70, C73, C75, C78, C81: 0.1uF; 0402-CAP
C71, C76, C79, C82: 10nF; 0402-CAP
C72: 10uF; 0402-CAP
LED4: LEDSML0603; SML0603
R36, R37, R38, R39: 0; 0402
R41: 4.7k; 0402-RES
R42: DNP; 0402-RES
R43: 10k; 0402-RES
S4: CHS04SLIDESWITCHA-PKG-VARIANT; CHS04SLIDESWITCH
U24: ICE40UP5K-SG48QFN48; LATTICE-QFN-48
U25: TLV757P; TLV757P-WSON

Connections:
FT4222_VOUT3V3: S4.2, S4.3; also elsewhere on the board
GND: C67.2, C68.2, C69.2, C70.2, C71.2, C72.2, C73.2, C74.2, C75.2, C76.2, C77.2, C78.2, C79.2, C80.2, C81.2, C82.2, R41.2, R42.1, U24.P$1 (PAD), U25.7 (PAD); also elsewhere on the board
ICE40_CRESET_B: R43.1, S4.1', U24.8 (CRESET_B)
ICE40_PIN02: LED4.A, U24.2 (IOB_6A)
ICE40_PIN03: U24.3 (IOB_9B)
ICE40_PIN04: U24.4 (IOB_8A)
ICE40_PIN06: U24.6 (IOB_13B)
ICE40_PIN07: U24.7 (CDONE)
ICE40_PIN09: U24.9 (IOB_16A)
ICE40_PIN10: U24.10 (IOB_18A)
ICE40_PIN11: U24.11 (IOB_20A)
ICE40_PIN12: U24.12 (IOB_22A)
ICE40_PIN13: U24.13 (IOB_24A)
ICE40_PIN14: R36.1, U24.14 (IOB_32A_SPI_SO)
ICE40_PIN15: R37.1, U24.15 (IOB_34A_SPI_SCK)
ICE40_PIN16: R38.1, R42.2, U24.16 (IOB_35B_SPI_SS)
ICE40_PIN17: R39.1, U24.17 (IOB_33B_SPI_SI)
ICE40_PIN18: U24.18 (IOB_31B)
ICE40_PIN19: U24.19 (IOB_29B)
ICE40_PIN20: U24.20 (IOB_25B_G3)
ICE40_PIN21: U24.21 (IOB_23B)
ICE40_PIN23: U24.23 (IOT_37A)
ICE40_PIN25: U24.25 (IOT_36B)
ICE40_PIN26: U24.26 (IOT_39A)
ICE40_PIN27: U24.27 (IOT_38B)
ICE40_PIN28: U24.28 (IOT_41A)
ICE40_PIN31: U24.31 (IOT_42B)
ICE40_PIN32: U24.32 (IOT_43A)
ICE40_PIN34: U24.34 (IOT_44B)
ICE40_PIN35: U24.35 (IOT_46B_G0)
ICE40_PIN36: U24.36 (IOT_48B)
ICE40_PIN37: U24.37 (IOT_45A_G1)
ICE40_PIN38: U24.38 (IOT_50B)
ICE40_PIN39: U24.39 (RGB0)
ICE40_PIN40: U24.40 (RGB1)
ICE40_PIN41: U24.41 (RGB2)
ICE40_PIN42: U24.42 (IOT_51A)
ICE40_PIN43: U24.43 (IOT_49A)
ICE40_PIN44: U24.44 (IOB_3B_G6)
ICE40_PIN45: U24.45 (IOB_5B)
ICE40_PIN46: U24.46 (IOB_0A)
ICE40_PIN47: U24.47 (IOB_2A)
ICE40_PIN48: U24.48 (IOB_4A)
ICE40_VCCIO: C67.1, C74.1, C75.1, C76.1, C77.1, C78.1, C79.1, C80.1, C81.1, C82.1, R43.2, S4.3', S4.4', U24.1 (VCCIO_2), U24.22 (SPI_VCCIO1), U24.33 (VCCIO_0), U25.4 (EN), U25.6 (IN)
ICE40_VCC_1V2: C68.1, C69.1, C70.1, C71.1, U24.5 (VCC_PIN5), U24.30 (VCC_PIN30), U25.1 (OUT)
ICE40_VCC_PLL: C72.1, C73.1, U24.29 (VCCPLL)
ICE40_VPP2V5: S4.2', U24.24 (VPP_2V5)
KL03_I2C0_SCL/KL03_LPUART0_TX: S4.1; also elsewhere on the board
KL03_I2C0_SDA/KL03_LPUART0_RX: R38.2; also elsewhere on the board
KL03_SPI_MISO/PAN1326_RTS: R36.2; also elsewhere on the board
KL03_SPI_MOSI/PAN1326_CTS: R39.2; also elsewhere on the board
KL03_SPI_SCK: R37.2; also elsewhere on the board
unnamed: LED4.C, R41.1
SCALED_SENSOR_SUPPLY: S4.4; also elsewhere on the board

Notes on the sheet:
Warp revision B
Authored 2015-2018 Phillip Stanley-Marbell
NO WARRANTY. See LICENCE.txt

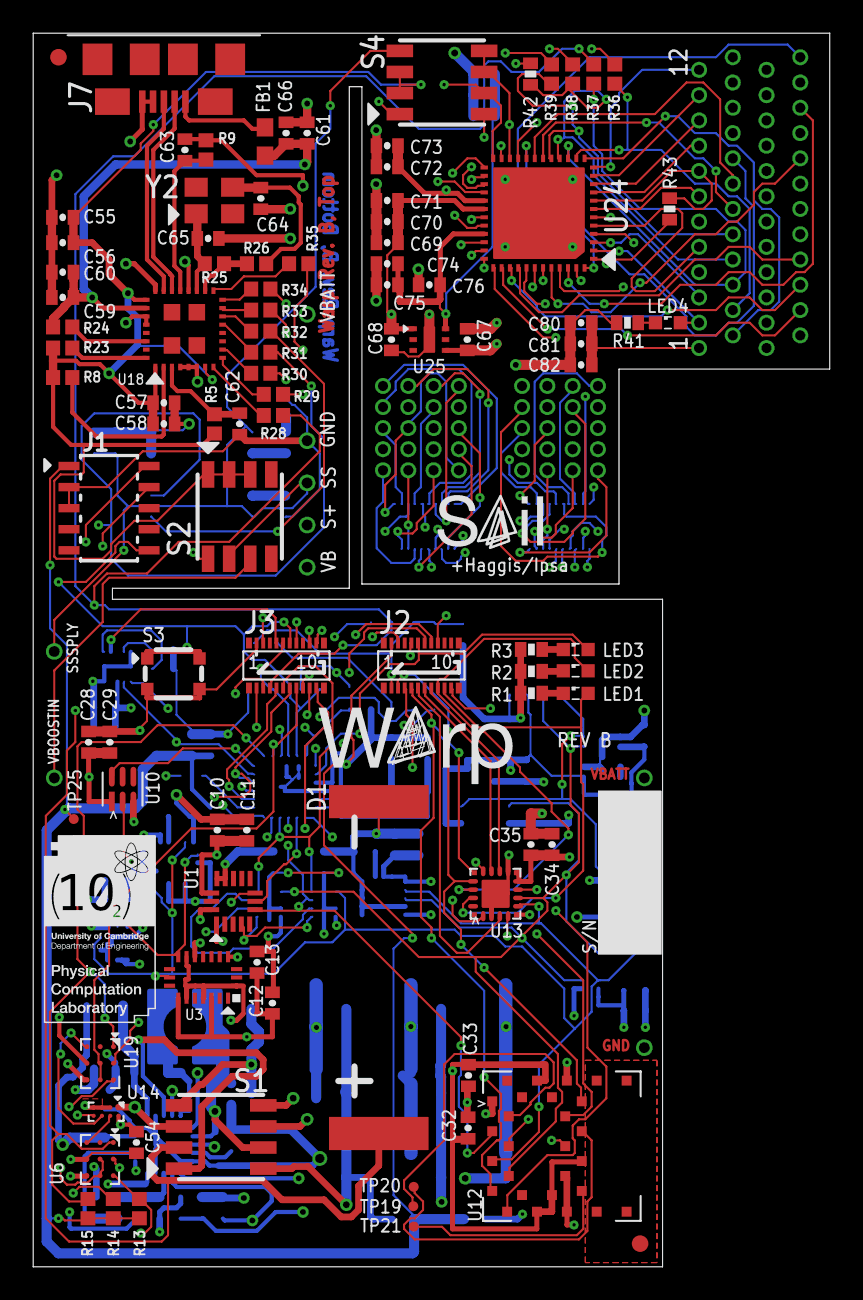
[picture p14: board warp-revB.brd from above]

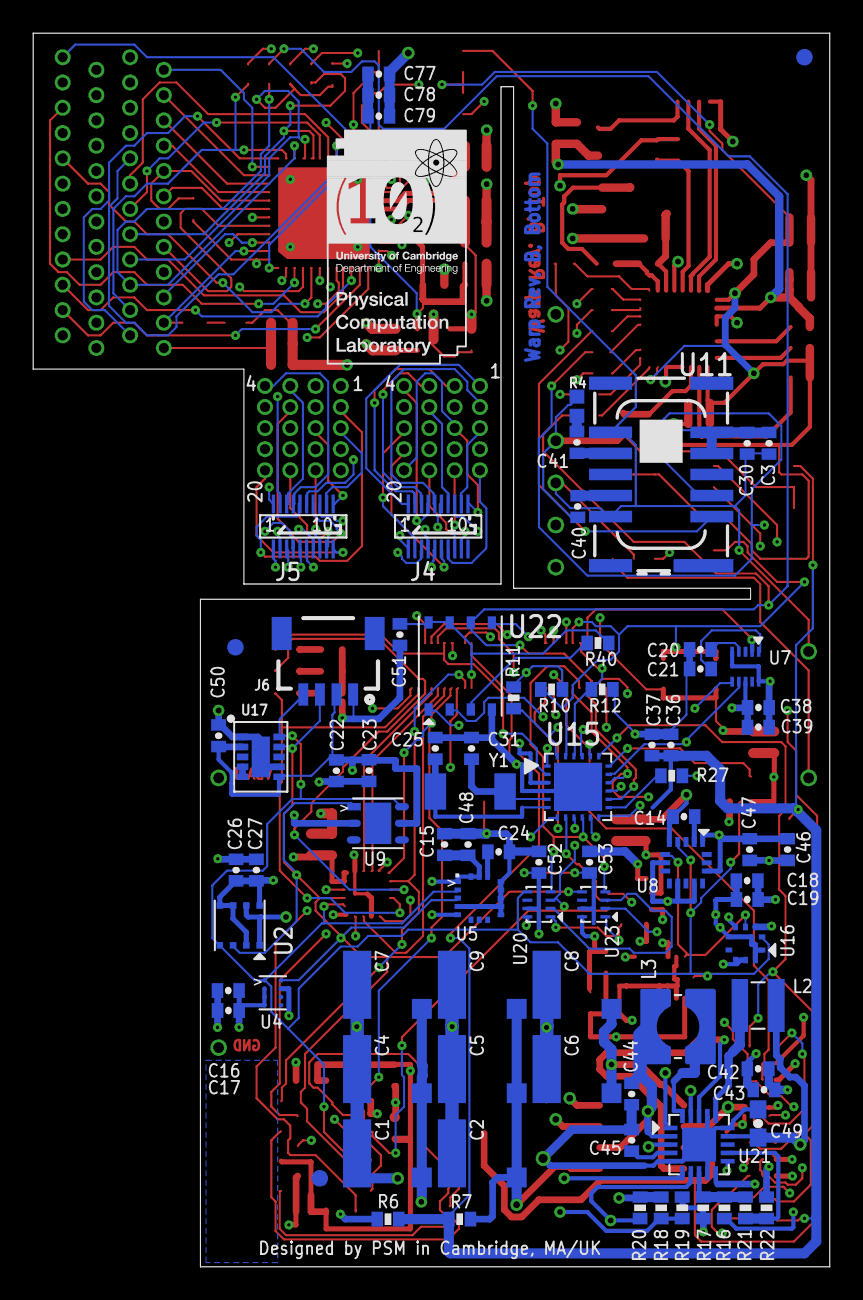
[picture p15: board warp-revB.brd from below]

Board: 10 copper layers, 48.0 x 74.3 mm, 180 parts (84 on the bottom side), 100 nets.

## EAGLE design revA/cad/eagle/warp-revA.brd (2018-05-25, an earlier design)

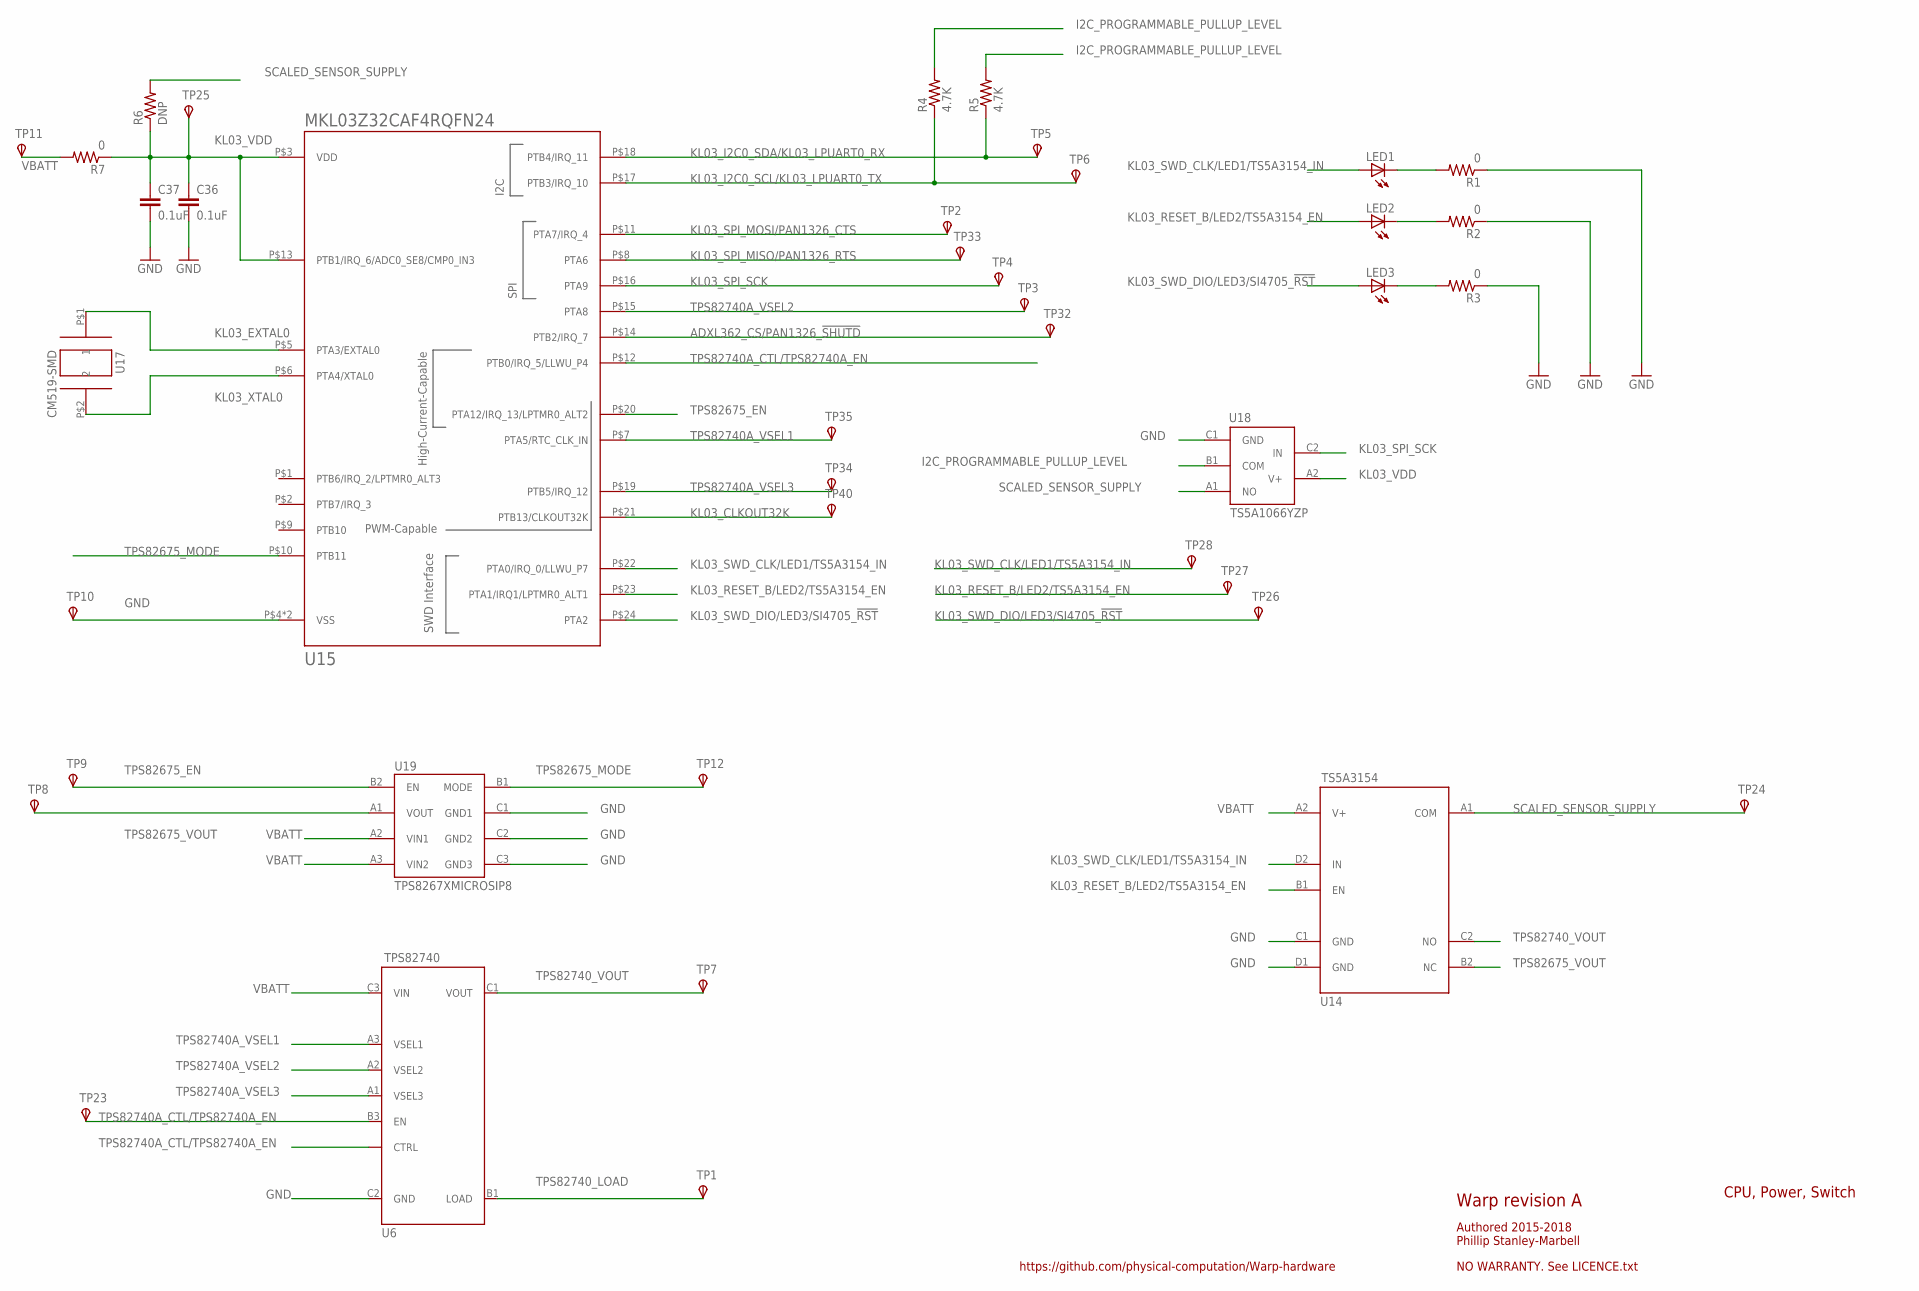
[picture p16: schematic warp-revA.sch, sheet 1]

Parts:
C36, C37: 0.1uF; 0402-CAP
LED1, LED2, LED3: LEDSML0603; SML0603
R1, R2, R3, R7: 0; 0402-RES
R4, R5: 4.7K; 0402-RES
R6: DNP; 0402-RES
TP1, TP2, TP3, TP4, TP5, TP6, TP7, TP8, TP9, TP10, TP11, TP12, TP23, TP24, TP25, TP26, TP27, TP28, TP32, TP33, TP34, TP35, TP40: TPSTP06R; TP06R
U6: TPS82740
U14: TS5A3154
U15: MKL03Z32CAF4RQFN24; MKL03Z32VFK4R
U17: CM519-SMD; CM519
U18: TS5A1066YZP; R-XBGA-N5
U19: TPS8267XMICROSIP8; MICROSIP-8

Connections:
ADXL362_CS/PAN1326_!SHUTD: TP32.TP, U15.P$14 (PTB2/IRQ_7); also elsewhere on the board
GND: C36.2, C37.2, R1.1, R2.1, R3.1, TP10.TP, U6.C2 (GND), U14.C1 (GND), U14.D1 (GND), U15.P$4 (VSS), U15.P$PAD (VSS), U18.C1 (GND), U19.C1 (GND1), U19.C2 (GND2), U19.C3 (GND3); also elsewhere on the board
I2C_PROGRAMMABLE_PULLUP_LEVEL: R4.2, R5.2, U18.B1 (COM)
KL03_CLKOUT32K: TP40.TP, U15.P$21 (PTB13/CLKOUT32K); also elsewhere on the board
KL03_EXTAL0: U15.P$5 (PTA3/EXTAL0), U17.P$1 (1)
KL03_I2C0_SCL/KL03_LPUART0_TX: R4.1, TP6.TP, U15.P$17 (PTB3/IRQ_10); also elsewhere on the board
KL03_I2C0_SDA/KL03_LPUART0_RX: R5.1, TP5.TP, U15.P$18 (PTB4/IRQ_11); also elsewhere on the board
KL03_RESET_B/LED2/TS5A3154_EN: LED2.A, TP27.TP, U14.B1 (EN), U15.P$23 (PTA1/IRQ1/LPTMR0_ALT1); also elsewhere on the board
KL03_SPI_MISO/PAN1326_RTS: TP33.TP, U15.P$8 (PTA6); also elsewhere on the board
KL03_SPI_MOSI/PAN1326_CTS: TP2.TP, U15.P$11 (PTA7/IRQ_4); also elsewhere on the board
KL03_SPI_SCK: TP4.TP, U15.P$16 (PTA9), U18.C2 (IN); also elsewhere on the board
KL03_SWD_CLK/LED1/TS5A3154_IN: LED1.A, TP28.TP, U14.D2 (IN), U15.P$22 (PTA0/IRQ_0/LLWU_P7); also elsewhere on the board
KL03_SWD_DIO/LED3/SI4705_!RST: LED3.A, TP26.TP, U15.P$24 (PTA2); also elsewhere on the board
KL03_VDD: C36.1, C37.1, R6.1, R7.1, TP25.TP, U15.P$3 (VDD), U15.P$13 (PTB1/IRQ_6/ADC0_SE8/CMP0_IN3), U18.A2 (V+)
KL03_XTAL0: U15.P$6 (PTA4/XTAL0), U17.P$2 (2)
unnamed: LED1.C, R1.2
unnamed: LED2.C, R2.2
unnamed: LED3.C, R3.2
SCALED_SENSOR_SUPPLY: R6.2, TP24.TP, U14.A1 (COM), U18.A1 (NO); also elsewhere on the board
TPS82675_EN: TP9.TP, U15.P$20 (PTA12/IRQ_13/LPTMR0_ALT2), U19.B2 (EN)
TPS82675_MODE: TP12.TP, U15.P$10 (PTB11), U19.B1 (MODE)
TPS82675_VOUT: TP8.TP, U14.B2 (NC), U19.A1 (VOUT)
TPS82740A_CTL/TPS82740A_EN: TP23.TP, U6.B2 (CTRL), U6.B3 (EN), U15.P$12 (PTB0/IRQ_5/LLWU_P4)
TPS82740A_VSEL1: TP35.TP, U6.A3 (VSEL1), U15.P$7 (PTA5/RTC_CLK_IN)
TPS82740A_VSEL2: TP3.TP, U6.A2 (VSEL2), U15.P$15 (PTA8)
TPS82740A_VSEL3: TP34.TP, U6.A1 (VSEL3), U15.P$19 (PTB5/IRQ_12)
TPS82740_LOAD: TP1.TP, U6.B1 (LOAD)
TPS82740_VOUT: TP7.TP, U6.C1 (VOUT), U14.C2 (NO)
VBATT: R7.2, TP11.TP, U6.C3 (VIN), U14.A2 (V+), U19.A2 (VIN1), U19.A3 (VIN2); also elsewhere on the board

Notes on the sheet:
Warp revision A
Authored 2015-2018 Phillip Stanley-Marbell
NO WARRANTY. See LICENCE.txt
https://github.com/physical-computation/Warp-hardware
CPU, Power, Switch


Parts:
C10, C11, C12, C13, C14, C16, C18, C20, C21, C23, C26, C27, C28, C38, C46, C47, C48: 0.1uF; 0402-CAP
C15: 10uF; 0402-CAP
C17, C22, C29, C39: 1uF; 0402-CAP
C19: 4.7uF; 0402-CAP
C24: 10nF (25V); 0402-CAP
C30: 10nF; 0402-CAP
TP22: TPTP06R; TP06R
U1: ADXL362
U2: BMP180
U3: BMX055
U4: HDC1000
U5: L3GD20H
U7: MAG3110
U8: MMA8451Q
U9: SI7021
U10: TCS3772
U11: TMP006B
U16: LPS25H

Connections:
ADXL362_CS/PAN1326_!SHUTD: U1.P$8 (!CS); also elsewhere on the board
GND: C10.2, C11.2, C12.2, C13.2, C14.2, C15.2, C16.2, C17.2, C18.2, C19.2, C20.2, C21.2, C22.2, C23.2, C24.2, C26.2, C27.2, C28.2, C29.2, C30.2, C38.2, C39.2, C46.2, C47.2, C48.2, U1.P$12 (GND), U1.P$13 (GND), U1.P$16 (GND), U2.P$7 (GND), U3.P$4 (GNDA), U3.P$6 (GNDIO), U3.P$12 (SDO2), U3.P$17 (SDO1), U3.P$20 (CSB3), U4.B2 (GND), U5.P$4 (I2C_SA0/SPI_SDO), U5.P$9 (RESERVED), U5.P$10 (RESERVED), U5.P$11 (RESERVED), U5.P$12 (GND), U5.P$13 (GND), U7.P$5 (GND), U7.P$10 (GND), U8.P$5 (GND), U8.P$7 (SA0), U8.P$10 (GND), U8.P$12 (GND), U9.P$2 (GND), U10.P$3 (GND), U11.A1 (DGND), U11.A2 (AGND), U16.P$3 (GND), U16.P$5 (I2C_SA0/SPI4_SDO), U16.P$8 (GND), U16.P$9 (GND); also elsewhere on the board
KL03_I2C0_SCL/KL03_LPUART0_TX: U2.P$5 (I2C_SCL), U3.P$9 (SCX), U4.A1 (SCL), U5.P$2 (I2C_SCL/SPI_SPC), U7.P$7 (SCL), U8.P$4 (SCL), U9.P$6 (SCL), U10.P$2 (SCL), U11.B3 (SCL), U16.P$2 (I2C_SCL/SPI_SPC); also elsewhere on the board
KL03_I2C0_SDA/KL03_LPUART0_RX: U2.P$6 (I2C_SDA/SPI_SDI), U3.P$11 (SDX), U4.A2 (SDA), U5.P$3 (I2C_SDA/SPI_SDI/SPI3_SDO), U7.P$6 (SDA), U8.P$6 (SDA), U9.P$1 (SDA), U10.P$6 (SDA), U11.C3 (SDA), U16.P$4 (I2C_SDA/SPI4_SDI/SPI3_SDIO); also elsewhere on the board
KL03_SPI_MISO/PAN1326_RTS: U1.P$7 (MISO); also elsewhere on the board
KL03_SPI_MOSI/PAN1326_CTS: U1.P$6 (MOSI); also elsewhere on the board
KL03_SPI_SCK: U1.P$4 (SCLK); also elsewhere on the board
L3GD20H_DEN: TP22.TP, U5.P$8 (DEN)
unnamed: C14.1, U8.P$2 (BYP)
unnamed: C21.1, U7.P$1 (CAP_A)
unnamed: C20.1, U7.P$4 (CAP_R)
unnamed: C24.1, U5.P$14 (CAP)
SCALED_SENSOR_SUPPLY: C10.1, C11.1, C12.1, C13.1, C15.1, C16.1, C17.1, C18.1, C19.1, C22.1, C23.1, C26.1, C27.1, C28.1, C29.1, C30.1, C38.1, C39.1, C46.1, C47.1, C48.1, U1.P$1 (VDDIO), U1.P$14 (VS), U2.P$2 (VDD), U2.P$3 (VDDIO), U3.P$3 (VDD), U3.P$7 (PS), U3.P$13 (VDDIO), U4.B1 (VDD), U4.C1 (ADR0), U4.D1 (ADR1), U5.P$1 (VDD_IO), U5.P$5 (I2C_VS_SPI_MODE_SELECT), U5.P$15 (RESERVED), U5.P$16 (VDD), U7.P$2 (VDD), U7.P$8 (VDDIO), U8.P$1 (VDDIO), U8.P$14 (VDD), U9.P$5 (VDD), U10.P$1 (VDD), U11.A3 (V+), U11.B1 (ADR1), U11.C1 (ADR0), U16.P$1 (VDD_IO), U16.P$6 (I2C_VS_SPI_MODE_SELECT/SPI_EN), U16.P$10 (VDD); also elsewhere on the board

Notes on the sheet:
I2C Address: 0x1C (SA0 -> GND)
I2C Address: Accel/Gyro/Mag --> 0x18/0x68/0x10 (SDO1/SDO2/CSB3-> GND/GND/GND)
I2C Address: 0x43 (ADR0/ADR1 --> VDD/VDD)
I2C Address: 0x5C (I2C_SA0-> GND)
I2C Address: 0x0E
I2C Address: 0x40
I2C Address: 0x6A (SA0 -> GND)
I2C Address 0x77
I2C Address: 0x29
I2C Address: 0x45 (ADR0-> VDD, ADR1-> VDD)
Warp revision A
Authored 2015-2018 Phillip Stanley-Marbell
NO WARRANTY. See LICENCE.txt
https://github.com/physical-computation/Warp-hardware
Sensors

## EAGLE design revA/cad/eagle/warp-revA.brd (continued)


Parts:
C32, C34: 0.1uF; 0402-CAP
C33: 10uF; 0402-CAP
C35: 22nF; 0402-CAP
TP13, TP14, TP15, TP16, TP17, TP18, TP19, TP20, TP21, TP37, TP38, TP39: TPTP06R; TP06R
U12: PAN1326B
U13: SI4705

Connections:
ADXL362_CS/PAN1326_!SHUTD: U12.P$16 (!SHUTD); also elsewhere on the board
GND: C32.2, C33.2, C34.2, C35.2, U12.P$1 (GND), U12.P$12 (GND), U12.P$14 (GND), U12.P$20 (GND), U13.P$3 (RFGND), U13.P$6 (!SEN), U13.P$12 (GND), U13.P$21 (GND); also elsewhere on the board
KL03_CLKOUT32K: U12.P$8 (SLOW_CLK_IN), U13.P$9 (RCLK); also elsewhere on the board
KL03_I2C0_SCL/KL03_LPUART0_TX: U12.P$5 (HCI_RX), U13.P$7 (SCLK); also elsewhere on the board
KL03_I2C0_SDA/KL03_LPUART0_RX: U12.P$6 (HCI_TX), U13.P$8 (SDIO); also elsewhere on the board
KL03_SPI_MISO/PAN1326_RTS: U12.P$4 (HCI_RTS); also elsewhere on the board
KL03_SPI_MOSI/PAN1326_CTS: U12.P$3 (HCI_CTS); also elsewhere on the board
KL03_SWD_DIO/LED3/SI4705_!RST: U13.P$5 (!RST); also elsewhere on the board
PAN1326B_AUD_CLK: TP39.TP, U12.P$19 (AUD_CLK), U13.P$17 (GPO3/DCLK)
PAN1326B_AUD_FSYNC: TP37.TP, U12.P$7 (AUD_FSYNC), U13.P$16 (DFS)
PAN1326B_AUD_IN: TP38.TP, U12.P$18 (AUD_IN), U13.P$15 (DOUT)
PAN1326B_AUD_OUT: TP20.TP, U12.P$17 (AUD_OUT)
PAN1326B_RF: TP21.TP, U12.P$13 (RF)
PAN1326B_TX_DBG: TP19.TP, U12.P$2 (TX_DBG)
SCALED_SENSOR_SUPPLY: C32.1, C33.1, C34.1, C35.1, U12.P$10 (MLDO_OUT), U12.P$11 (CL1.5_LDO_IN), U12.P$15 (MLDO_IN), U12.P$22 (VDD_IO), U13.P$10 (VD), U13.P$11 (VA); also elsewhere on the board
SI4705_FMI: TP13.TP, U13.P$2 (FMI)
SI4705_GPO1: TP18.TP, U13.P$19 (GPO1)
SI4705_GPO2: TP17.TP, U13.P$18 (GPO2/!INT)
SI4705_LOUT: TP16.TP, U13.P$14 (LOUT)
SI4705_LPI: TP14.TP, U13.P$4 (LPI)
SI4705_ROUT: TP15.TP, U13.P$13 (ROUT)

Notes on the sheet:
I2C Address: 0x11 (nSEN -> GND)
Warp revision A
Authored 2015-2018 Phillip Stanley-Marbell
NO WARRANTY. See LICENCE.txt
https://github.com/physical-computation/Warp-hardware
Radios


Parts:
C1, C2, C3, C4, C5, C6, C7, C8, C9: XH414HGIV01E
C40: 10uF; 0402-CAP
C41: 4.7uF; 0402-CAP
D1, D2, D3, D4, D5, D6, D7, D8, D9: TEMD5080
D10: CHARGE_PATH_DIODE; SML0603
IC1: TPS61070DDC; TSOT23-6_DDC
L1: 4.7uH; 0603
R8: 1M; 0402-RES
R9: 200k; 0402-RES

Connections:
GND: C1.-, C2.-, C3.-, C4.-, C5.-, C6.-, C7.-, C8.-, C9.-, C40.2, C41.2, D1.P$1, IC1.2 (GND), R9.1; also elsewhere on the board
unnamed: IC1.1 (SW), L1.2
unnamed: IC1.4 (FB), R8.2, R9.2
unnamed: D1.P$2, D2.P$1
unnamed: D2.P$2, D3.P$1
unnamed: D3.P$2, D4.P$1
unnamed: D4.P$2, D5.P$1
unnamed: D5.P$2, D6.P$1
unnamed: D6.P$2, D7.P$1
unnamed: D7.P$2, D8.P$1
unnamed: D8.P$2, D9.P$1
unnamed: D9.P$2, D10.A
VBATT: C1.+, C2.+, C3.+, C4.+, C5.+, C6.+, C7.+, C8.+, C9.+, C40.1, IC1.5 (VOUT), R8.1; also elsewhere on the board
VBOOSTIN: C41.1, D10.C, IC1.3 (EN), IC1.6 (VBAT), L1.1

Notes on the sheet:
These capacitors are 0.08F each, for a total of 0.72F
Warp revision A
Authored 2015-2018 Phillip Stanley-Marbell
NO WARRANTY. See LICENCE.txt
https://github.com/physical-computation/Warp-hardware
Charging


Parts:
C42, C43: 33pF; 0402-CAP
C44, C45: 0.1uF; 0402-CAP
R10, R11, R12, R16, R17, R18, R19, R20, R21, R22, R23, R24, R25, R26, R27, R28, R29, R30, R31, R35: 0; 0402-RES
U20: CM519-SMD; CM519
U21: MKL03Z32CAF4RQFN24; MKL03Z32VFK4R
U22: SDCARD-PADS

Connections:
CPU1_EXTAL0: C42.1, U20.P$1 (1), U21.P$5 (PTA3/EXTAL0)
CPU1_PTA5: R22.2
CPU1_PTA6: R16.2, U22.8 (DAT1)
CPU1_PTB1: R28.1, U22.9 (DAT2)
CPU1_PTB2: R19.2
CPU1_PTB3: R11.2
CPU1_PTB4: R10.2
CPU1_PTB5: R23.2
CPU1_PTB6: R29.1
CPU1_PTB10: R31.1
CPU1_PTB13: R24.2
CPU1_RESET: R26.2
CPU1_SWD_CLK: R25.2
CPU1_SWD_DIO: R27.2
CPU1_XTAL0: C43.1, U20.P$2 (2), U21.P$6 (PTA4/XTAL0)
FAKE_SDIO_CLK: R20.2, U22.5 (CLK)
FAKE_SDIO_CS: R30.1, U22.1 (CD/DAT3)
FAKE_SDIO_DI: R18.2, U22.2 (CMD)
FAKE_SDIO_DO: R35.1, U22.7 (DAT0)
GND: C42.2, C43.2, C44.2, C45.2, U21.P$4 (VSS), U21.P$PAD (VSS), U22.3 (VSSA), U22.6 (VSSB); also elsewhere on the board
KL03_RESET_B/LED2/TS5A3154_EN: R21.2; also elsewhere on the board
KL03_SWD_CLK/LED1/TS5A3154_IN: R17.2; also elsewhere on the board
KL03_SWD_DIO/LED3/SI4705_!RST: R12.2; also elsewhere on the board
unnamed: R28.2, U21.P$13 (PTB1/IRQ_6/ADC0_SE8/CMP0_IN3)
unnamed: R29.2, U21.P$1 (PTB6/IRQ_2/LPTMR0_ALT3)
unnamed: R30.2, U21.P$2 (PTB7/IRQ_3)
unnamed: R31.2, U21.P$9 (PTB10)
unnamed: R35.2, U21.P$10 (PTB11)
unnamed: R10.1, U21.P$18 (PTB4/IRQ_11)
unnamed: R11.1, U21.P$17 (PTB3/IRQ_10)
unnamed: R12.1, U21.P$11 (PTA7/IRQ_4)
unnamed: R16.1, U21.P$8 (PTA6)
unnamed: R17.1, U21.P$16 (PTA9)
unnamed: R18.1, U21.P$15 (PTA8)
unnamed: R19.1, U21.P$14 (PTB2/IRQ_7)
unnamed: R20.1, U21.P$12 (PTB0/IRQ_5/LLWU_P4)
unnamed: R21.1, U21.P$20 (PTA12/IRQ_13/LPTMR0_ALT2)
unnamed: R22.1, U21.P$7 (PTA5/RTC_CLK_IN)
unnamed: R23.1, U21.P$19 (PTB5/IRQ_12)
unnamed: R24.1, U21.P$21 (PTB13/CLKOUT32K)
unnamed: R25.1, U21.P$22 (PTA0/IRQ_0/LLWU_P7)
unnamed: R26.1, U21.P$23 (PTA1/IRQ1/LPTMR0_ALT1)
unnamed: R27.1, U21.P$24 (PTA2)
VBATT: C44.1, C45.1, U21.P$3 (VDD), U22.4 (VDD); also elsewhere on the board

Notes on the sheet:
Layer stack up:
1: Signal
2: Gnd
3: signal
14: vbatt
15: gnd
16: Signal
4: Signal
5: scaled sensor supply
6: gnd
7: Signal
Warp revision A
Authored 2015-2018 Phillip Stanley-Marbell
NO WARRANTY. See LICENCE.txt
https://github.com/physical-computation/Warp-hardware
AUX Appendage



Board: 10 copper layers, 36.1 x 55.2 mm, 148 parts (61 on the bottom side), 86 nets.

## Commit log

2018-05-25 Basic files for release of revA
    [warp-revA-bom.xlsx, warp-revA-centroid.csv, warp-revA.brd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]
2018-06-17 Added Fusion360 CAD file
    [warp-revA.f3d]
2018-06-26 add more snaps design to the enclosure
2018-06-28 issue should be solved now
    [enclosure-design.f3d]
2018-06-28 Enclosure pictures
2018-06-29 Mechanical design for revB
    [warp-revB.f3d]
2018-07-03 first draft
    [RevB-Enclosure.f3d]
2018-07-03 add switch design
    [switch.f3d]
2018-07-06 Enclosure design
    [RevB-Enclosure.f3d, revB-enclosure-design.f3d, switch.f3d]
2018-07-06 Switch design
    [revB-switch-design.f3d]
2018-07-06 file added
    [warp-revB.f3d]
2018-07-06 Directory cleanup
    [revB-enclosure-design.f3d, revB-switch-design.f3d, warp-revB.f3d]
2018-07-09 Changes in design
    [Enclosure-Design-RevB.f3d, Switch-Design-RevB.f3d, revB-enclosure-design.f3d]
2018-07-10 Add Square enclosures
    [Square-Enclosure-Design-RevB-Bolts.f3d, Square-Enclosure-Design-RevB-NoBolts.f3d]
2018-07-10 Changes to the switch design
    [Switch-Design-RevB.f3d]
2018-08-01 Modified version
    [Revised-Enclosure-Design-revB.f3d]
2018-08-01 Moved Revised-Enclosure-Design-revB.f3d -> Enclosure-Design-RevB.f3d
    [Enclosure-Design-RevB.f3d, Revised-Enclosure-Design-revB.f3d]
2018-08-08 Change of BOM
    adding a column stating details
    [warp-revA-bom.xlsx]
2018-08-08 Updated changed of BOM
    [warp-revA-bom.xlsx]
2018-08-08 File modified
    [Enclosure-Design-RevB.f3d]
2018-08-09 Added wristband design
    [Wristband-Design-revB.f3d]
2019-05-29 Initial import of revision B design.
    [warp-revB.brd, warp-revB.sch]
2019-07-24 Added datasheets for revB
    [iCE40UP 5k Pinout.xlsx]
2019-10-08 Update README.md
    Fixing switches
2019-10-09 Added revC eagle files using new fork
    [warp-revC.brd, warp-revC.sch]
2019-10-16 Adding how to power with a SMU
2019-11-08 Removed FPGA microvias and rerouted
    [warp-revC.brd, warp-revC.sch]
2019-11-14 MAG3110 with FXOS8700CQ. Added BOM
    [warp-revC-BOM.csv, warp-revC.brd, warp-revC.sch]
2019-12-20 Corrected footprint errors
    [warp-revC.brd, warp-revC.sch]
2020-01-07 Corrections to footprints
    [warp-revC-BOM.csv, warp-revC.brd, warp-revC.sch]
2020-02-10 Commit of CAD design, BOM and datasheets for 1st production run of Warp-revC
    [BOM_E1174766-B.csv, bq25505(70_Design_Help_V1_3.xlsx, iCE40UP 5k Pinout-1.xlsx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]
2021-09-26 Tree cleanup
    [bq25505(70_Design_Help_V1_3.xlsx, iCE40UP 5k Pinout-1.xlsx]

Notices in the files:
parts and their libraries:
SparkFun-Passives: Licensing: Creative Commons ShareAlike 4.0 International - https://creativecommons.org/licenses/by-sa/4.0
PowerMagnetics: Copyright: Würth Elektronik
